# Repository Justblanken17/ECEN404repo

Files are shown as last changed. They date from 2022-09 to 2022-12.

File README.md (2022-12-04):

# ECEN404repo
reposit

Below Will detail what the Growable Space Habitat is, where to find files in this repo, as well as the deliverables at the end of 404 as well as hw to setup the project to run:

What is the Growable Space Habitat and our part in it? 

The Growable Space Habitat is a self-sustaining enclosure that is capable of keeping track of its health as well as make adjustments when needed. The Power Management
System is capable of supplying power to the MCU and AI/Data Processing systems while charging the battery and protecting it at the same time. The MCU system houses all of
the peripherals in the system such as sensors, fans, solenoids that monitor the habitat. The AI/Data Processing system is capable of classifying if plants within the 
system are healthy through 2 machine learning (ML) models. All of the data that s collected from the MCU, is then sent to the pi to be processed, which can send commands
to the MCU to adapt the habitat, ie, turn on the fan or solenoid etc. Everything that is sent to the pi and stored is then pushed to our User Interface System. 
The User Interface system takes the data that was pushed into the database and displays it on an app for the user to view. Data that can be viewed in the app include 
the different MCU boards, and for each of the boards, sensor data can be seen on graphs as well as historical data. The user can also see the images that the camera has
taken as well as if the plant is in a healthy state or not. 

## Our Deliverables for 404: ## 
1. User Interface:
    a. Be able to update real time photos and any of the sensor data on to graphs and display images through the app on the phone from 2 MCU boards
    b. firebase database communication with pi to receive data then send to the app for viewing.

2. AI/Data Processing:
     a. Working tomato leaf data set to be able to classify healthy or not
     b. working bell pepper leaf data set to be able to classify healthy or not (was not required but was completed for supplemental material)
     c. communicates with MCU as well as database

3. MCU:
     a. Control of O2, Temp/Humidity, CO2, Liquid Level, Water Flow, solenoid, fan. (for analog, the joystick is good enough for validation, since we do not have controlled substances of any of the analog sensor gases, as well as the voltage output that we get on the ethylene being good enough validation for the Analog type)
     b. Communicate all of the collected data from the mcu to the Pi
     c. Control other peripherals (solenoid and fan).(solenoid "clicking" is sufficient since there are not valves to "open/close" and fan being controlled on/off)

4. Power Management System  
     a. Provide power to the Pi and MCU systems
     b. Charge battery at same time that it is discharging (sun will not be out so power supply will mimic the solar panel) through the board and the controller.
     c. Protect the battery
     d. Monitoring was not able to work, talked it over with our sponsor Dr. Rising and she is aware and okay with it being passed down to the next ECEN team working on the project. The cell monitor is now an optional piece to this subsystem. 

5. Github Repository:
    a. Everything related to the project including schematics, designs, datasheets etc
    b. detailed write ups containing the purpose of each of the subsystems
    c. detailed description of the progress that was made and what needs to be done for the next team, also possible steps that they should take (advice).
   d. Shared with Rohith, Dr. Lusher and Dr. Rising

## How to navigate through our repo: ## 

In our Repo, the 4 of us have our own folders that have specific titles to make it easy to navigate. 
All datasheets, test scripts, altium designs and everything else related to the project is in this repo.

How to setup the project: 
1. The battery needs to first be connected to the terminal block on the BMS (positive on top most, negative on bottom most). The output of the BMS is to be connected to the MPPT controller. Any buck converters that are used need to be plugged into the mppt controller on the load termnals. These buck converters are sending power through wires to the MCU boards and the pi through a USB-A to USB-C cable. A solar panel, or or power supply can be plugged into the PV portion of the MPPT. The MCUs have already had the memory flashed, so the only setup there is connecting the sensors to it which will already be connected. Powering the MCUs come from the output of the buck converters to the terminal block on the MCU board. There is no setup for the User Interface side since it updates the data automatically as it is received. For the AI/Data Processing system the setup consists of running the scripts and then letting the programs do what they are told to do. Our projectwas meant to be autonomous, so that very little, to no human interference is necessary. 

Thanks!

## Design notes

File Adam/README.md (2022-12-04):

The idrectories stord here is the abstracted code for the MCU Firmware, Rsapberry Pi, Jupyter Notebook for training the binarry classifiers, and testing scripts for individual and system functionality.

## FIRMWARE ##

Each of the folders in the Firmware directory corresponds to the source and header file for each sensor.

## MACHINE_LEARNING ##

The folders store the jupyter nnotebooks that creates the data augmentation, train dataset, train csv, test dataset, model training.

## Test_Scripts ##

The python scripts here test the individual functionlity for of the system process to request i2c data, send data to database, classify, control cameras. etc.

## Running the system ##

Assuming that the system being used is the current image of the pi used, the following steps must be followed. In order to run main.py, the pi needs to have in its own sandbox i.e. virtual environment since Tensorflow has dependancies that affect the pi from running.

To activate the virtual environment:

cd Desktop/Project

source env/bin/activate

Adter it is activated mode back to the home directory and head to the test directory which is currently named Project_1:

cd ~
cd Desktop/Project_1

Run the serial_test script ot make sure that the serial data and serial clock line is intact and can receive data from the MCU:
python serial_test.py

Once it is verified and the corect values are being received, then head back to the home directory and proceed to the Demo directory:
cd ~
cd Demo

Run the main.py script so that it will constantly classify, retrieve data, and send data:
python main.py

## NOTE: ##
If a different database is used, you must change the db.ini file so that it can push data to the correct database. This was abstracted for ease of use in future changes of the database.

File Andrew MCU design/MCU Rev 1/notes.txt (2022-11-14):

1.8V regulator keeps breaking. MCU chip likely is drawing more than the rated 150mA.
LED power indicator circuit does not work.

Used 12MHz crystal oscillator, this means the clock configuration is max 198MHz, unlike the max 200MHz the curiosity 2.0 dev board is capable of.
Dev board link: https://www.microchip.com/en-us/development-tool/DM320209

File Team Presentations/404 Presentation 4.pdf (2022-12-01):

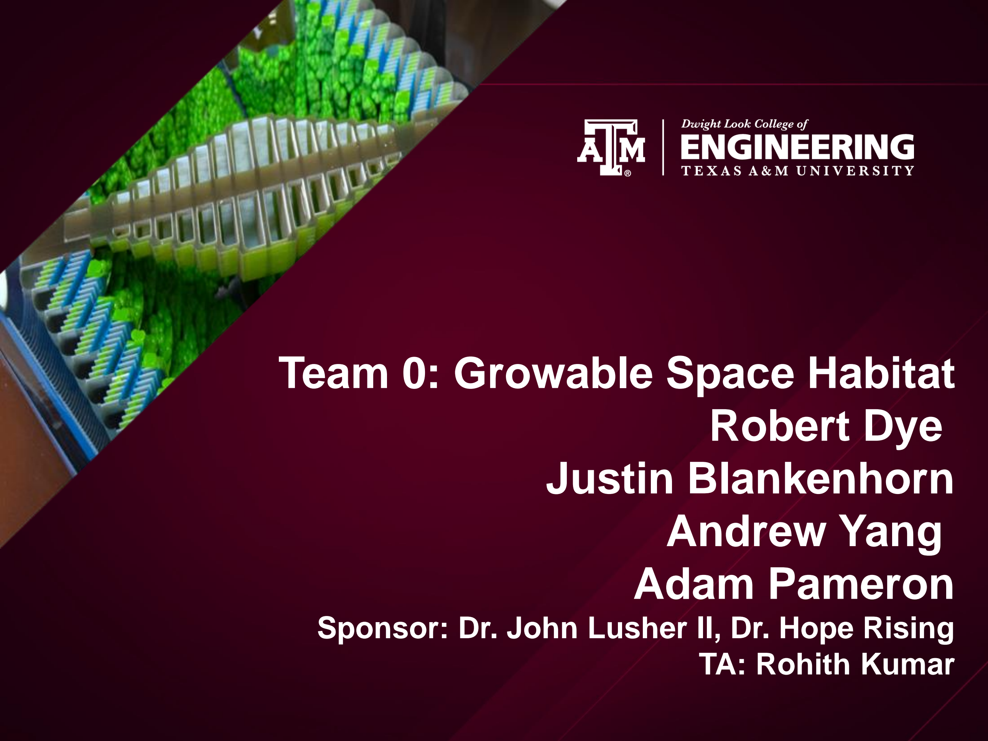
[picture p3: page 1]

# Team 0: Growable Space Habitat Robert Dye Justin Blankenhorn Andrew Yang Adam Pameron

### Sponsor: Dr. John Lusher II, Dr. Hope Rising TA: Rohith Kumar

# Project Summary

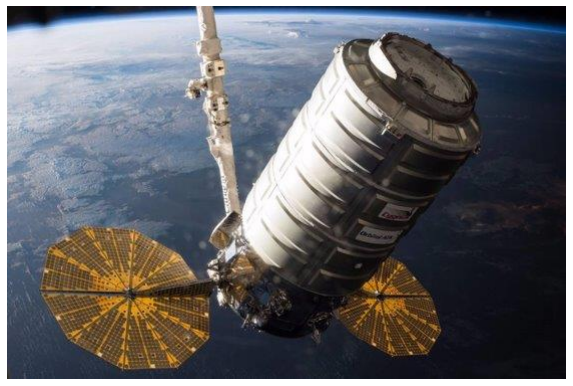
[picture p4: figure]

## - Current space operations require constant resupply

### – Costly ($20,000 per kg) – Inefficient and wasteful

## - Long term space missions need a sustainable food source

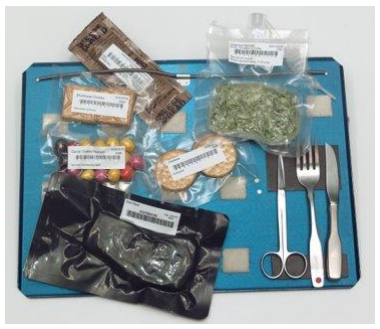
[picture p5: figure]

## - Project provides electrical infrastructure for a self-sustaining system capable of recycling agricultural products

# Project/Subsystem Overview

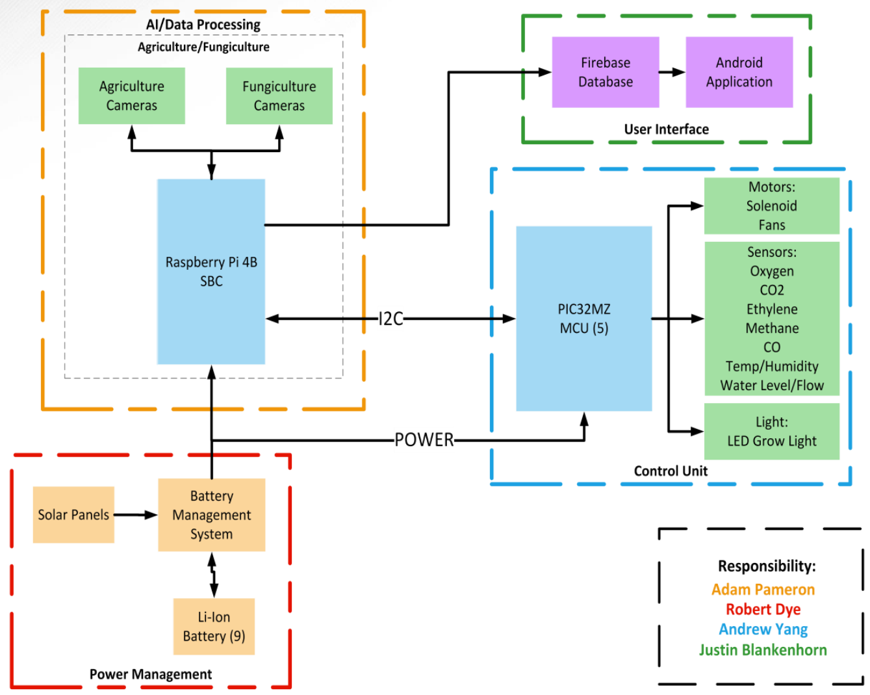
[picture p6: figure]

# Major Project Changes Since Last Time

Power Management:
- None
User Interface:
- None
AI/Data Processing:
- None
Microcontroller:
- None

## AI/Data Processing Subsystem

Adam Pameron

# - Create binary classifier using Convolutional Neural Network (CNN) Model

## – Baby Spinach

# - Collect sensor data from 5 microcontrollers - Send sensor data to database

# AI/Data Processing Subsystem

Adam Pameron
Accomplishments since last presentation

Ongoing progress/problems and plans until the next presentation

- Perform Stratified Cross Validation with augmented RGB Dataset
- Vertical Flip
- Gaussian Noise
- Blur
- Shearing
- Isolated each cameras to take photos at an interval period
- Built application code to repeat routines (classify, send image and state)
- Interfacing with microcontrollers using serial communication to request data, and validate all sensors data is collected and accurate

## AI/Data Processing Subsystem – Camera 1 and Camera 2 Photos

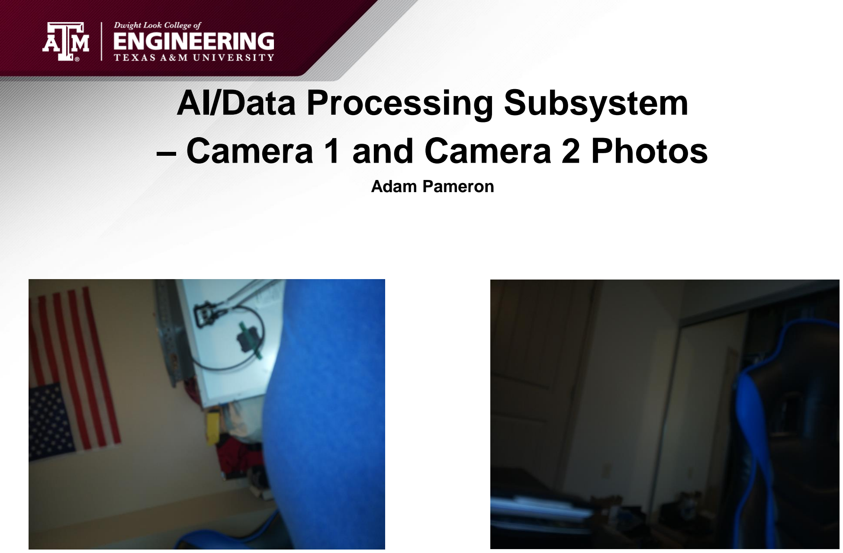
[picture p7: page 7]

Adam Pameron

## AI/Data Processing Subsystem – Camera 3 and Camera 4 Photos

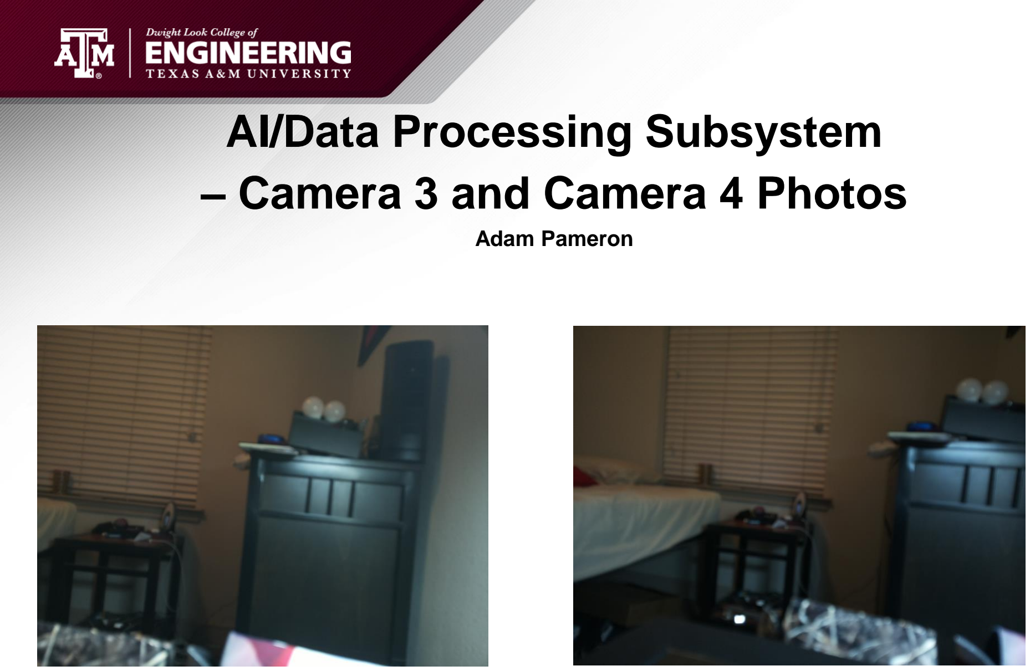
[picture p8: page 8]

Adam Pameron

## AI/Data Processing Subsystem

## - Total Size of Dataset

Adam Pameron

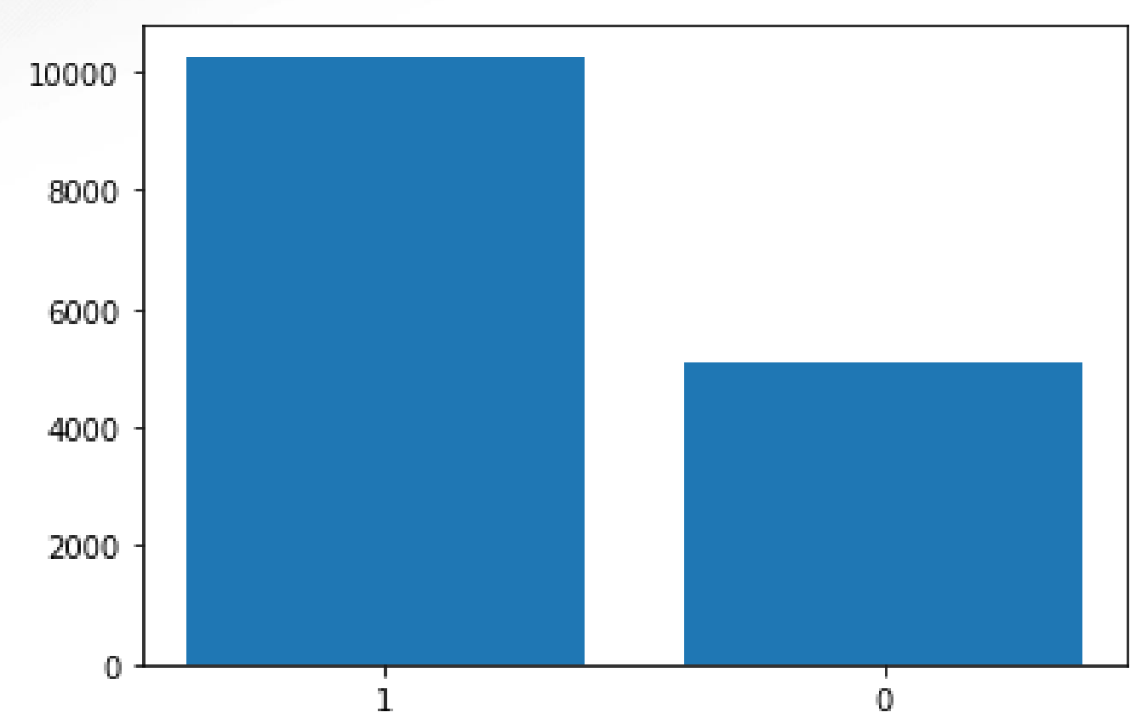
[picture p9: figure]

Healthy Set [0]: 5,084
Yellow Leaf Curl Set [1]: 10,264 Total Number of Images: 15,348

## AI/Data Processing Subsystem

## – with Gaussian Noise

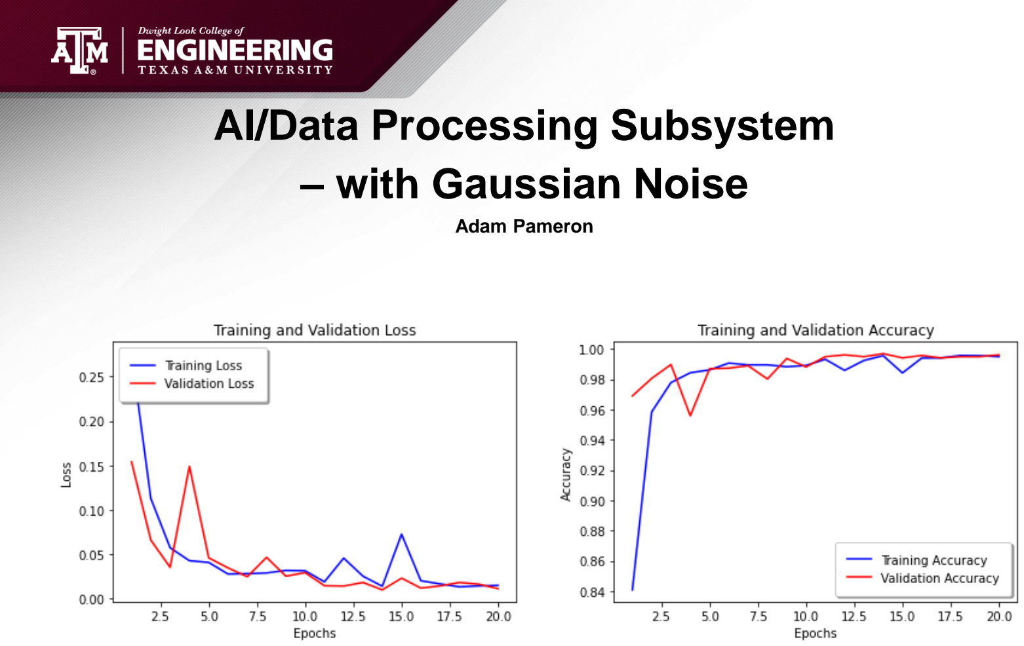
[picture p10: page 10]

Adam Pameron

## AI/Data Processing Subsystem

## – with Gaussian Noise

Adam Pameron

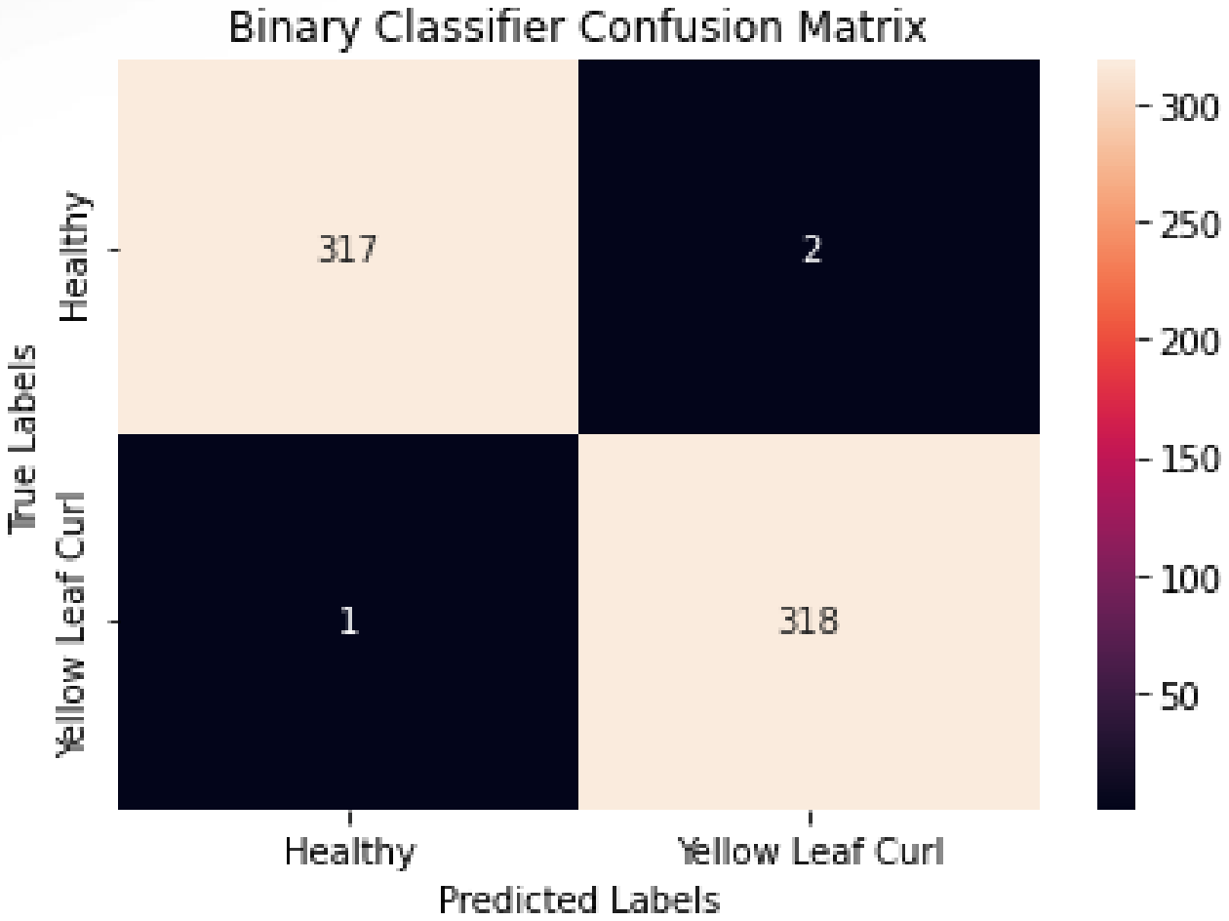
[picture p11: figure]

# - Provide power to PCBs that house the microcontrollers as well as the pi that will be used to control AI subsystem - BMS monitoring - Charging

# Power Management

Robert Dye

# Power Management

Robert Dye
Accomplishments since last presentation

Ongoing progress/problems and plans until the next presentation
- Soldered all components
- Powered MCU Subsystem
- Powered AI/Data Processing Subsystem
- Designed, Routed all 4 analog sensor circuits
- Keep performing testing on the BMS
- Code monitoring chips with BQ Studio

# Power Management

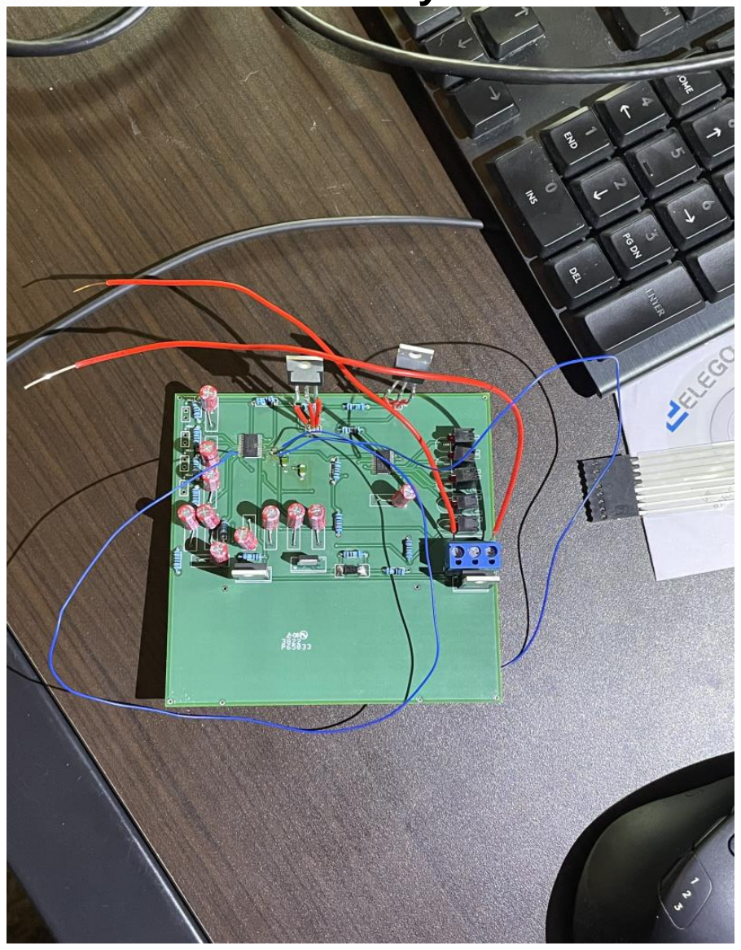
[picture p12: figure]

Robert Dye

# Power Management

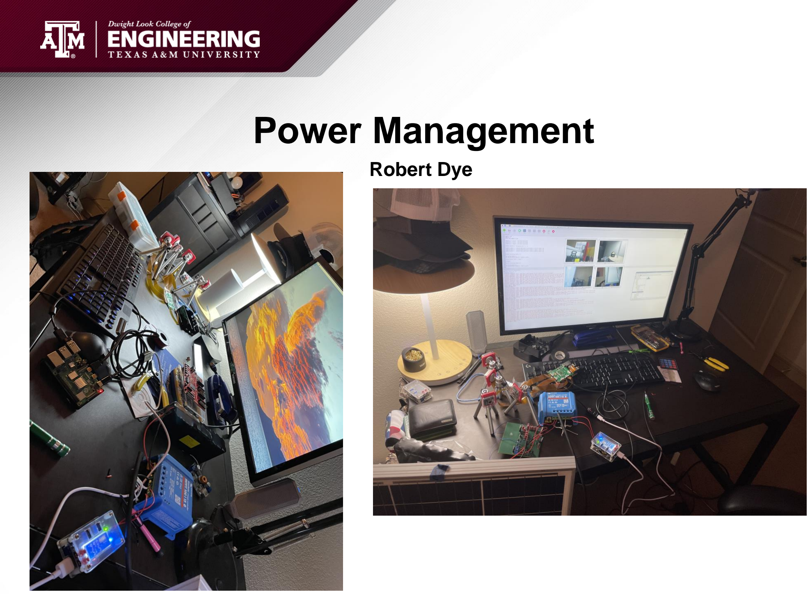
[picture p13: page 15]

Robert Dye

# Power Management

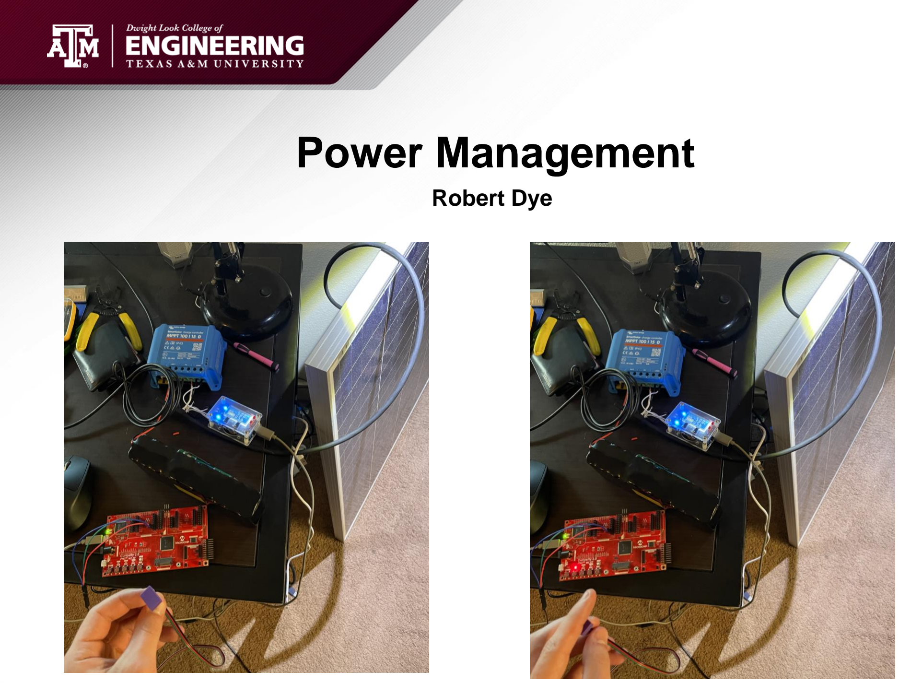
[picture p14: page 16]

Robert Dye

## Microcontroller

Andrew Yang

## - 200 Peripherals modularized between 5 microcontrollers

- 20 Oxygen, 20 CO2, 20 NO2, 20 Methane,

## 20 Ethylene, 20 Carbon monoxide, 12 Temp/Humidity, 4 water level, 4 water flow sensors

- 9 types of sensors using I2C, UART, Analog,

## or digital communication - 38 solenoids and 26 fans controlled using GPIO + switching circuit

# Microcontroller

Andrew Yang

Accomplishments
since last presentation

Ongoing progress/problems and plans until the next presentation
- Verified Water Level Sensor operation
- Designed Analog Sensor circuits
- Soldered over half of all components for the MCU
- Verify Temperature/Humidity I2C sensor operation
- Verify UART sensor operation
- Implement PWM logic for water flow sensor
- Design I2C multiplexer circuit for fan and solenoid switching

# Microcontroller

Andrew Yang

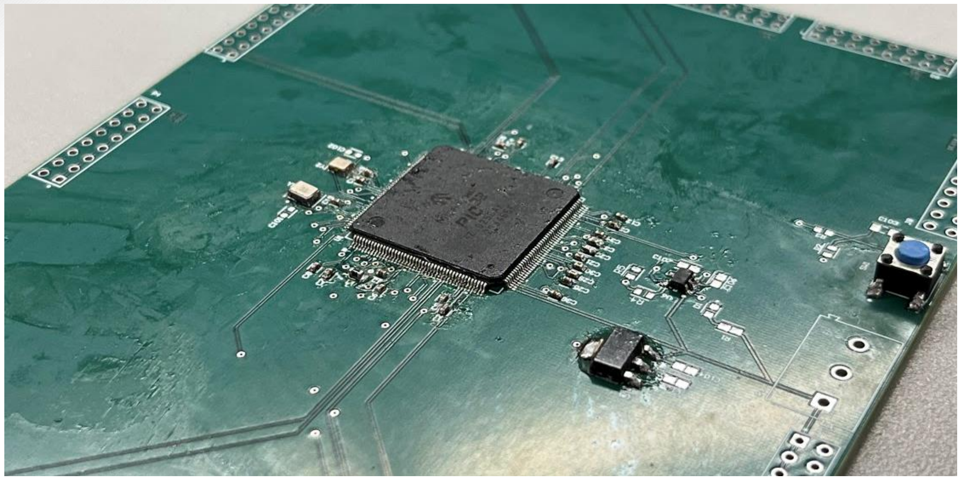
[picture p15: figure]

# Microcontroller

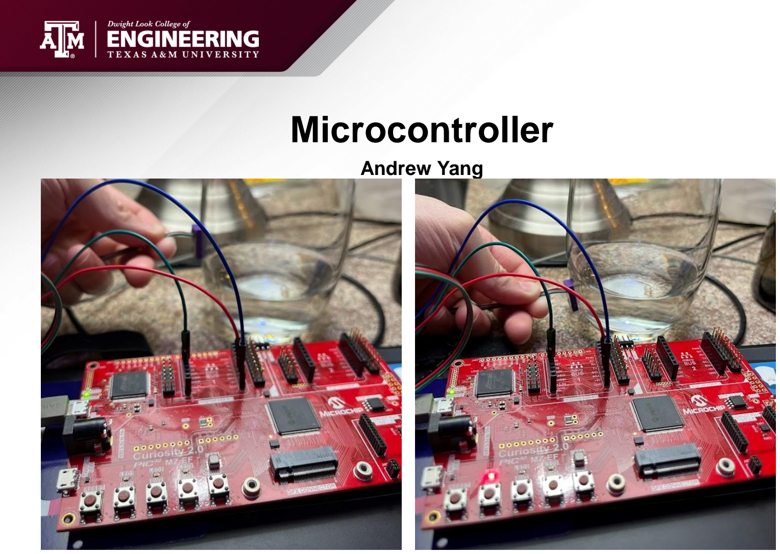
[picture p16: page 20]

Andrew Yang

# Microcontroller

Andrew Yang

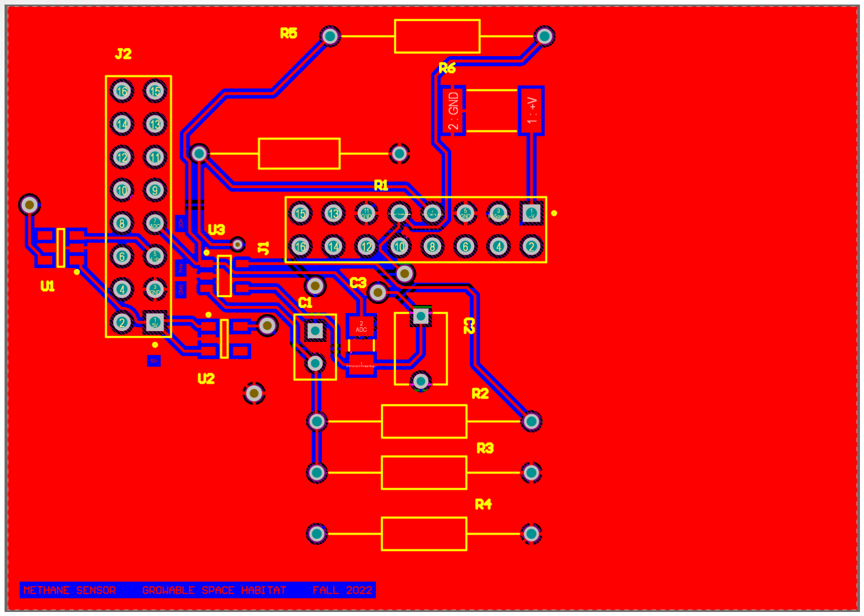
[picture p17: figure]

# Microcontroller

Andrew Yang

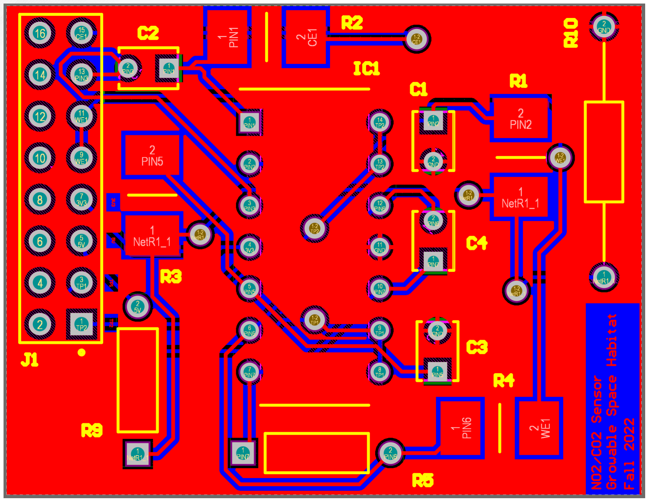
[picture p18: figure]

# Microcontroller

Andrew Yang

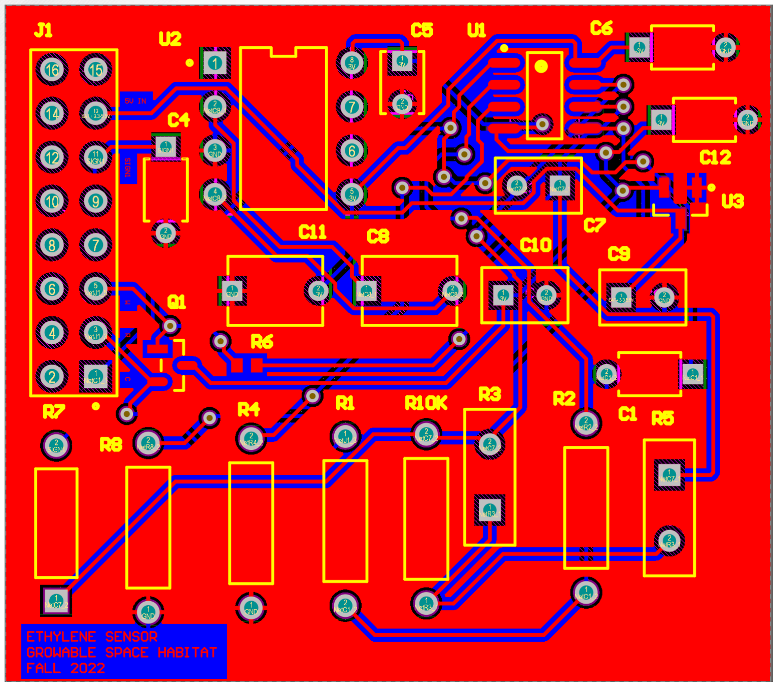
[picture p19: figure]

# User Interface

## - Display Data from MCU sensors on app - Visualize sensor values over time - Display camera pictures on app

# User Interface

Justin Blankenhorn

Accomplishments since last presentation

Ongoing progress/problems and plans until the next presentation
- Created Graphs for all sensors
- Differentiated graphs between Second + Minutes
- Included Axis's and scroll view for graph
- Improve formatting on graphs,
- Help on other subsystems

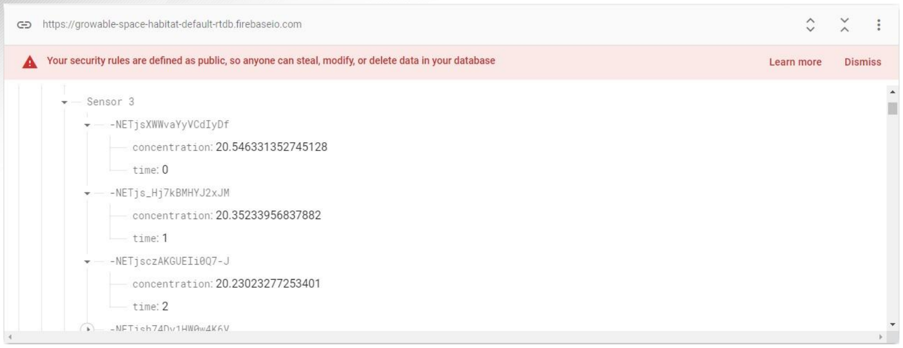
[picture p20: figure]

# User Interface

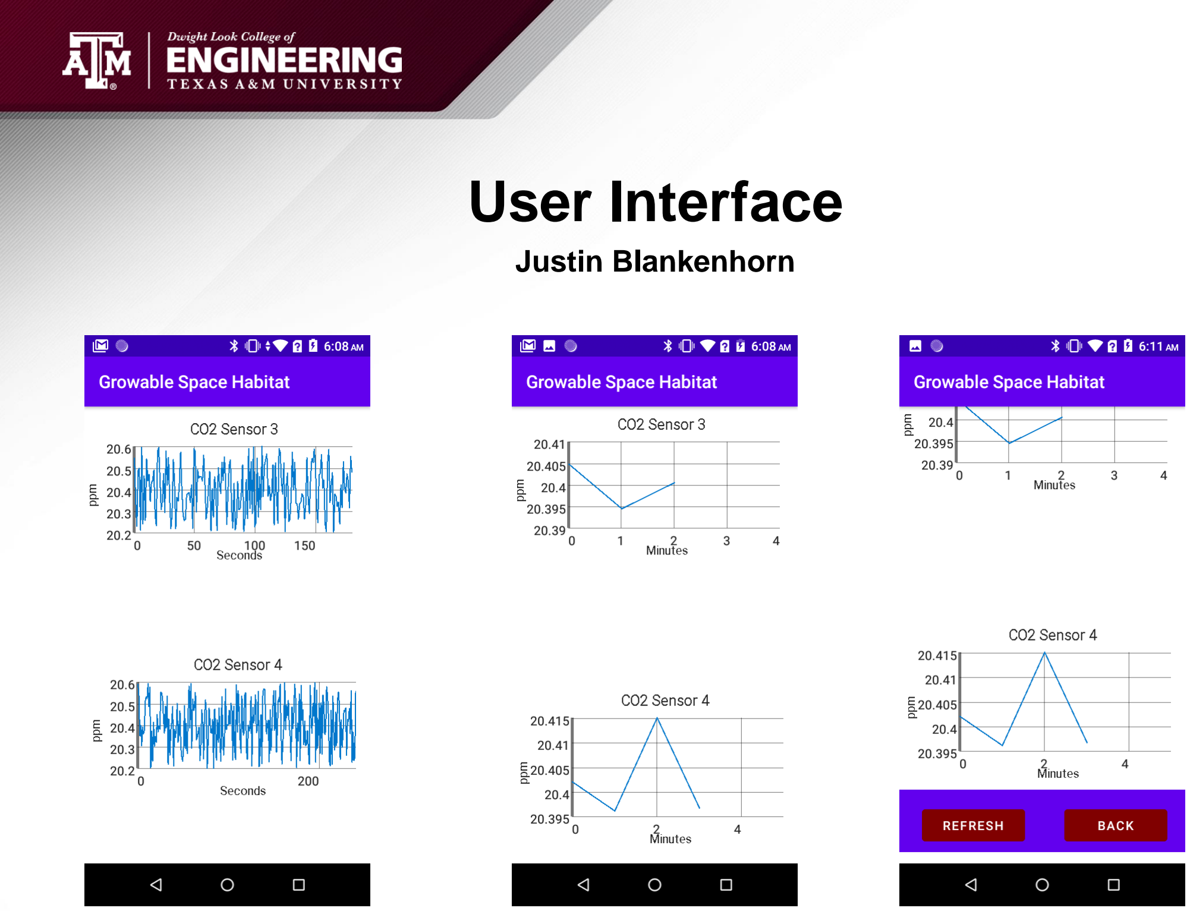
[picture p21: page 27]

Justin Blankenhorn

# Execution & Plan

# THANK YOU!

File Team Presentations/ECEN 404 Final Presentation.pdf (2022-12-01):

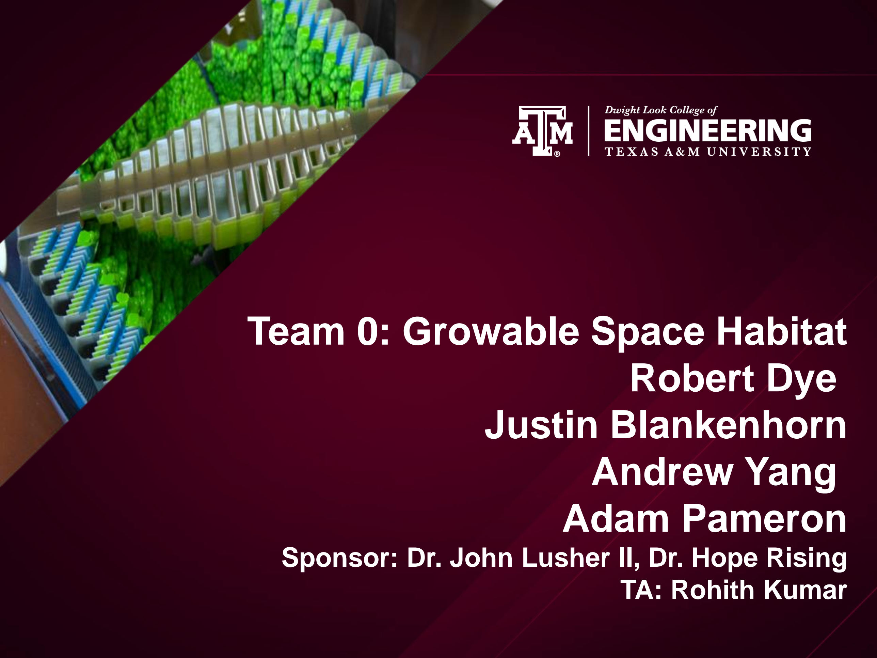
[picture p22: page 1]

# Team 0: Growable Space Habitat Robert Dye Justin Blankenhorn Andrew Yang Adam Pameron

### Sponsor: Dr. John Lusher II, Dr. Hope Rising TA: Rohith Kumar

# Project Overview

## - Current space operations require constant resupply

### – Costly ($20,000 per kg) – Inefficient and wasteful

## - Long term space missions need a sustainable food source


## - Project provides electrical infrastructure for a self-sustaining system capable of recycling agricultural products

# System-Level Requirements

- Power Management-
– Power MCU, AI/Data Processing – Charge battery through solar panel – Monitor battery pack
- MCU-
– Control Peripherals
– 1 of each type of sensor (I2C, Analog, UART, Digital (External clock)
– Replacing 1 analog with 2 extra others (Temp/Humidity, solenoid)
- AI/Data Processing-
– Binary Classifying model for tomato leaf as well as oyster mushroom (proxy data) – Reliably request data from MCU and send the data to the database
- User Interface-
– Display data from MCU sensors on an app
– Graph sensor values over time, Graph health of plant (1-healthy, 0-not) – Display camera pictures

# Project/Subsystem Block Diagram

## AI/Data Processing Accomplishments

Adam Pameron

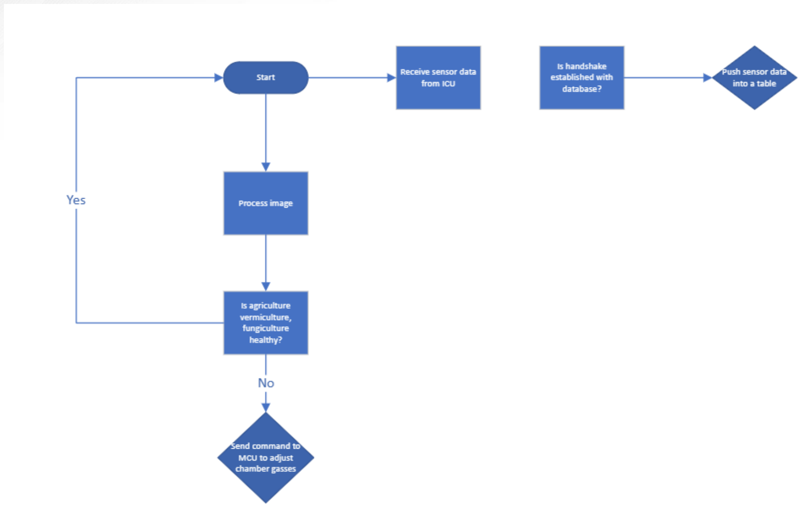
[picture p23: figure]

## AI/Data Processing Subsystem

## – Train Accuracy 4 Folds

Adam Pameron

## AI/Data Processing Subsystem

## – Validation Accuracy 4 Folds

Adam Pameron

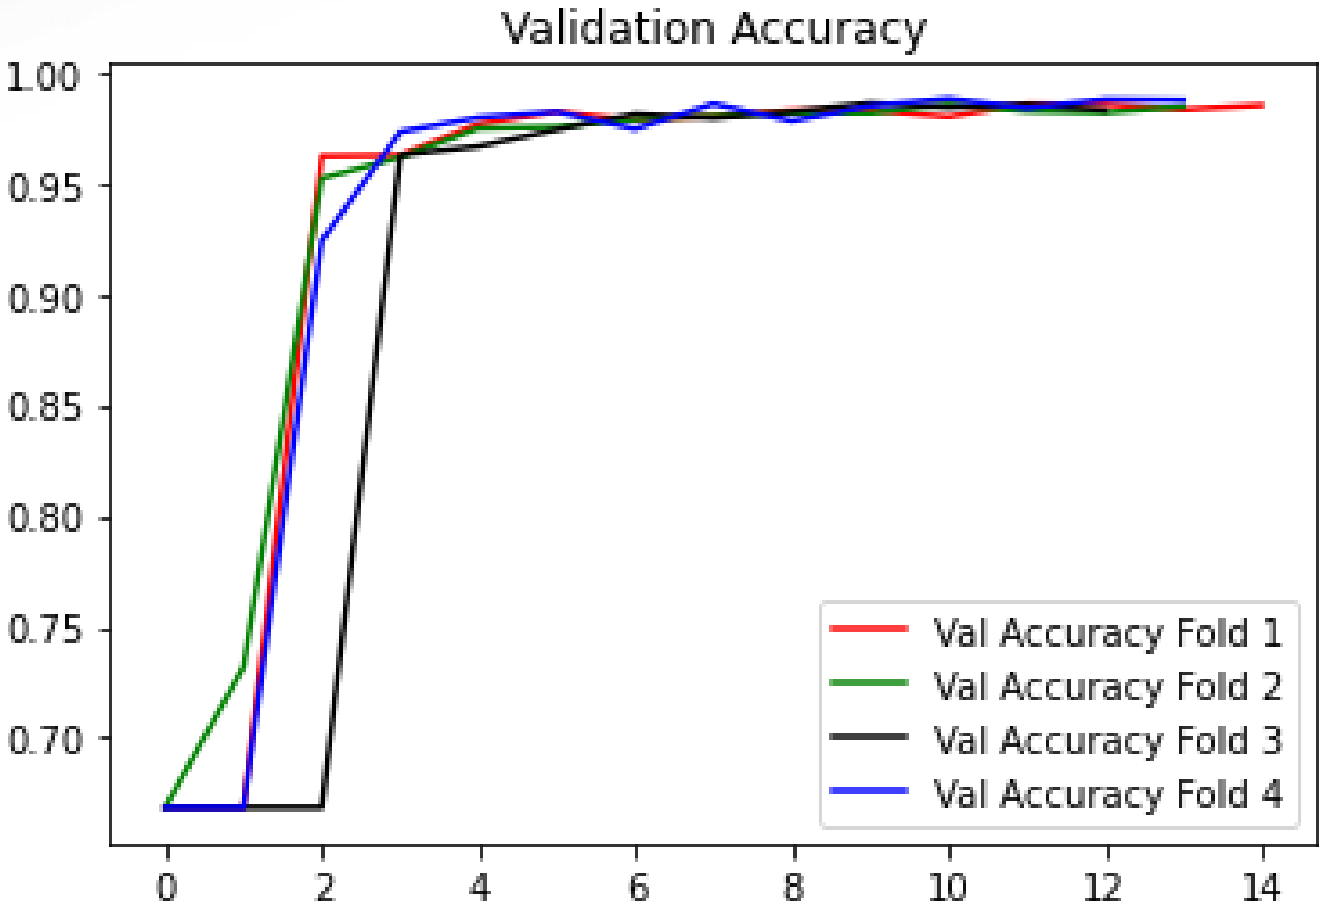
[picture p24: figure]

## AI/Data Processing Subsystem

## – Validation Accuracy 4 Folds

Adam Pameron

## AI/Data Processing Subsystem

## – Training and Validation Accuracy Fold 4

Adam Pameron

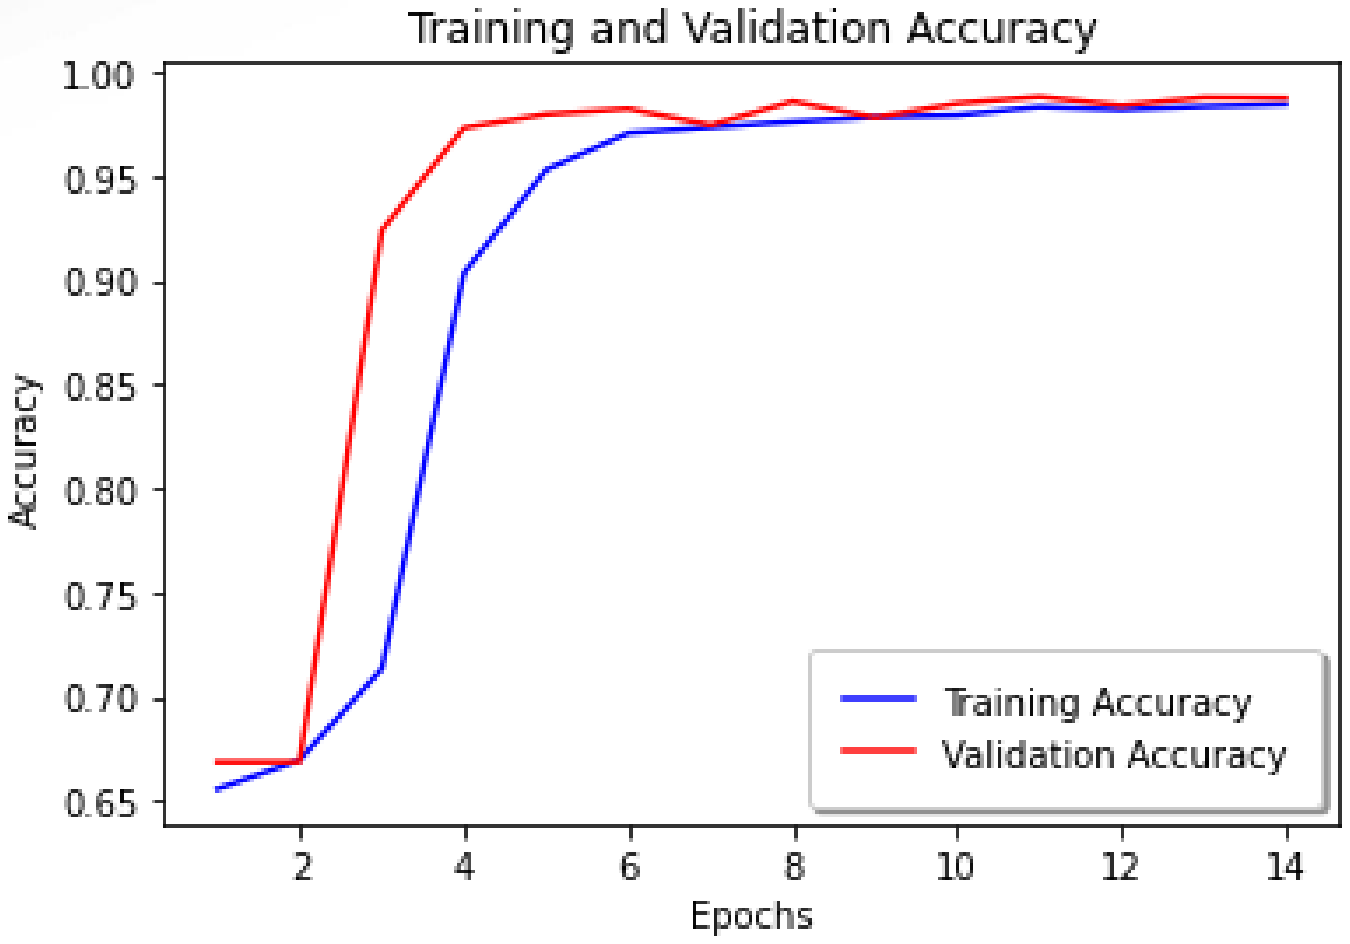
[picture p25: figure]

## AI/Data Processing Subsystem

## – Confusion Matrix Fold 4

Adam Pameron

## AI/Data Processing Subsystem

## – Pi and PIC32 CO2 Values

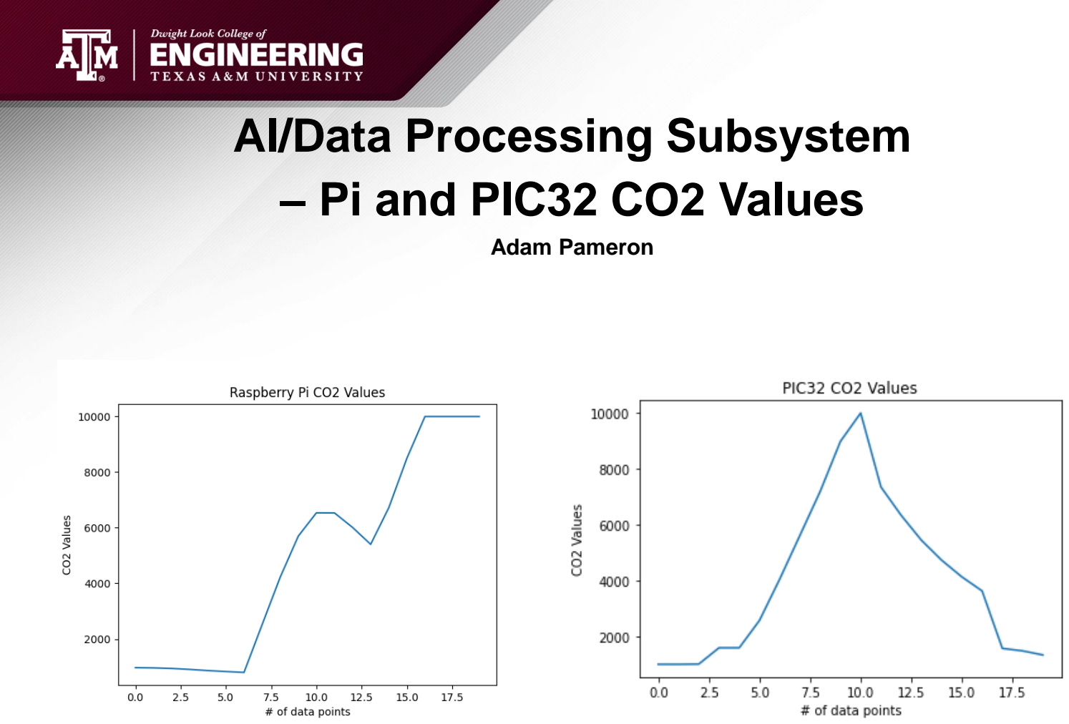
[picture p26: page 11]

Adam Pameron

## AI/Data Processing Subsystem

## – Arduino and PIC32 O2 Values

Adam Pameron

## AI/Data Processing Subsystem


Adam Pameron

# Power Management Accomplishments

Robert Dye

- BMS PCB
- Charging/discharging/power delivery
- Overcurrent Protection
- Design and solder 4 analog sensor circuits and PCBs with Andew


## Power Management Accomplishments Robert Dye

## Power Management Accomplishments Robert Dye


## Power Management Accomplishments Robert Dye

## Power Management Accomplishments Robert Dye


## Power Management Accomplishments Robert Dye

## Power Management Accomplishments Robert Dye


# Power Management

Robert Dye

# Power Management Previous Graphs

Robert Dye

# Power Management - Graphs from video

Robert Dye; Bat Voltage (V); Current (A)

Battery Voltage vs. Time

Current vs. Time

Time (hr:min:sec)

# Microcontroller Accomplishments

Andrew Yang

- Designed and soldered PIC32MZ microcontroller
- Designed and soldered 3 analog sensor circuits and PCBs with Robert
- Wrote firmware to operate water flow, temp/humidity, CO2, O2, water level, water flow sensor, solenoid, and fan with Adam


## Microcontroller Accomplishments Andrew Yang


## Microcontroller Accomplishments Andrew Yang

## Microcontroller Accomplishments Andrew Yang


## Microcontroller Accomplishments Andrew Yang

## Microcontroller Accomplishments Andrew Yang


## Microcontroller Accomplishments Andrew Yang

# User Interface Accomplishments

- Display real time sensor data
- Displaying graph's of sensor data of time, with different windows of duration
- Display camera pictures


# User Interface – General Format

Justin Blankenhorn

# User Interface – Validating edge cases 1


# User Interface – Validating edge cases 2

# Data Integration


# Data Integration


# System and Validation Results Videos


# System and Validation Results Videos


# System and Validation Results Videos


# System and Validation Results Full Video


# Conclusion Requirements

•Power Management-
•Built a BMS PCB that can power 2 other systems and charge battery via solar through BMS
•Built separate sensor circuits required to run the sensors
•MCU-
•Built PCB that can control various peripherals
- Built separate sensor circuits required to run the sensors
•AI/Data Processing-
•User Interface-
•Created and app and database where data can be displayed, analyzed, and pushed through

# Conclusions Learned

- Designing of PCB schematics and boards
- Microchip programming
- Concise reading of datasheets
- Reading convolution and neural networks
- Database/app creation and integration
- Sensor configurations, sensor amplifying techniques
- Microcontroller coding
- Cross team communication
- Project and time management skills
- If it can go wrong, it will go wrong

# Conclusion What Went Right and Wrong

- Rights-
- AI/Data Processing machine learning model classification
- App/Database Creation
- Integration of all 4 subsystems went smoothly
- Powering/Charging
- Control of different peripherals through both dev board and MCU
- Wrongs:
- Multiple design errors and other issues caught after PCBs soldered, had to re do designs
- Monitoring of pack and cell issues (contact with Dr. Lusher and TI) no resolutions
- Initial approach with mySQL database, changed to firebase for easier integration

# Project Mitigation

- Tasks to try to get done by demo
- Potentially 1 of the Analog sensors to work (replace with 2 others)
- Potential battery pack monitoring

# THANK YOU!

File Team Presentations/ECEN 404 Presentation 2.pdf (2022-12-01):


# Team 0: Growable Space Habitat Robert Dye Justin Blankenhorn Andrew Yang Adam Pameron

### Sponsor: Dr. John Lusher II, Dr. Hope Rising TA: Rohith Kumar

# Project Summary


## - Current space operations require constant resupply

### – Costly ($20,000 per kg) – Inefficient and wasteful

## - Long term space missions need a sustainable food source


## - Project provides electrical infrastructure for a self-sustaining system capable of recycling agricultural products

# Project/Subsystem Overview


# Major Project Changes Since Last Time

Power Management:
- Finalize 1 complete system by end of semester
User Interface:
- Converted to firebase
AI/Data Processing:
- Only working on baby spinach, no oyster mushroom
Microcontroller:
- Finalize 1 complete system by end of semester

# Project Timeline

Milestone | Expected Time
Obtain significant data for charging of battery pack | September 9
Order BMS PCB | September 9
Order MCU PCB | September 9
Integrate Raspberry Pi and 5 MCUs | September 17
Integrate all sensors | September 23
Solder all BMS PCB components | October 12
Solder all MCU PCB components | October 14
Finalize and debug all BMS connections | October 23
Integrate Raspberry Pi and Database | October 30
Retrieve Baby Spinach Data from Horticulture Team and create CNN Model | October 30
Finalize and debug all sensors | October 30

## AI/Data Processing Subsystem

Adam Pameron

# - Create binary classifier using Convolutional Neural Network (CNN) Model

## – Baby Spinach – Oyster Mushroom

# - Collect sensor data from 5 microcontrollers - Send sensor data to database

# AI/Data Processing Subsystem

Adam Pameron
Accomplishments since last presentation

Ongoing progress/problems and plans until the next presentation

- Perform data augmentation with data set
- Grayscale
- Vertical Flip
- Gaussian Blur
- Shearing
- Even number of data
- Request data from I2C with oxygen sensor
- Send trend data to Firebase Database
- Waiting for Horticulture Team to fully grow Healthy and Nitrogen Deficient Baby Spinach to collect images [est. October]
- Send images to Firebase database
- Interfacing with microcontrollers using serial communication to request data, and validate all sensors data is collected and accurate
- Build application code to repeat all routines (classify, request data, send data) at a set time

## AI/Data Processing Subsystem - Parameters

Adam Pameron


Modified LeNet Architecture

## AI/Data Processing Subsystem


Adam Pameron

## AI/Data Processing Subsystem

Adam Pameron


## AI/Data Processing Subsystem

Adam Pameron


## - Send oxygen data to Firebase – Time – Concentration

# - Provide power to PCBs that house the microcontrollers as well as the pi that will be used to control AI subsystem - BMS monitoring - Charging

# Power Management

Robert Dye

# Power Management

Robert Dye
Accomplishments since last presentation | Ongoing progress/problems and plans until the next presentation
- Performed extensive testing on battery and solar panel with smaller loads • Ordered PCB | • Perform same tests with a heavier load • Solder Components on PCB once it arrives • Help MCU subsystem

# Power Management


Robert Dye

## Microcontroller

Andrew Yang

## - 200 Peripherals modularized between 5 microcontrollers

- 20 Oxygen, 20 CO2, 20 NO2, 20 Methane,

## 20 Ethylene, 20 Carbon monoxide, 12 Temp/Humidity, 4 water level, 4 water flow sensors

- 9 types of sensors using I2C, UART, Analog,

## or digital communication - 38 solenoids and 26 fans controlled using GPIO + switching circuit

# Microcontroller

Andrew Yang

Accomplishments
since last presentation

Ongoing progress/problems and plans until the next presentation
- Redesigned MCU PCB
- Verified Oxygen I2C sensor operation
- Ordered new MOSFET for
solenoid switching
- Verify Temperature/Humidity I2C sensor operation
- Verify UART sensor operation
- Implement PWM logic for water flow sensor
- Design op-amp circuit and verify analog sensor operation
- Design I2C multiplexer circuit for fan and solenoid switching

# Microcontroller


Andrew Yang

# Microcontroller

Andrew Yang


# Microcontroller

Andrew Yang


# Microcontroller


Andrew Yang

Expected Result from Arduino

Result from Microchip Dev Board

# User Interface

## - Display Data from MCU sensors on app - Visualize sensor values over time - Display camera pictures on app

# User Interface

Justin Blankenhorn

Accomplishments since last presen tation | Ongoing progress/problems and plans until the next presentation
- Established connection between Android Studio and Firebase App • Set up Firebase database sensor data display on app for 3 MCU units | • Add display from other MCU units • Display images to app using firebase • Develop graphs for sensor data over time

# User Interface


Justin Blankenhorn

# Parts Ordering Status

Susbsytem | Item | Quantity | Price
AI/ Data Processing Subsystem | Raspberry Pi 4 8GB Kit | 1 | $169.95
| Arducam IMX519 Quad-Camera Kit | 1 | $169.99
| Arducam Camera Case and Mini Tripod | 4 | $11.99
Power Management Subsystem | 100 watt solar panel | 2 | $100
| BQ78350DBTR-R1A Fuel Guage | 10 | $4.00
| BQ7693000DBT Battery Monitor | 10 | $4.00
| 14.8V 13Ah Battery Pack | 6 | $194.00
| DC Power Supply | 1 | N/A
| Victron MPPT Controller | 1 | $137
| DROK Buck Converter | 10 | $14.00
| PCB | 5 | $63.64
Control Unit Subsystem | PIC32MZ2025DAK176-V/2J | 10 | $19.58
| Gravity: Electrochemical Oxygen Sensor | 10 | $43.12
| 004-0-0053 CO2 Sensor | 8 | $53.36
| 110-507 NO2 Sensor | 4 | $20.00
| IR33BC Methane Sensor | 4 | $262.63
| ME3-C2H4 Ethylene Sensor | 8 | $91.95
| SEN0485 Liquid Level Sensor | 8 | $9.90
| SEN0227 Temperature/Humidity Sensor | 8 | $22.50
| 110-102 CO Sensor | 8 | $20.00
| PCB | 5 | $126.37
| PG164140 Pickit4 Programmer | 2 | $65.32
| Mini solenoid | 4 | $12.49
| NF-A4x10 5V Fan | 8 | $13.95
| Water Flow Sensor | 4 | $10.99
| 2N7000 N-MOS | 2 | $5.50
| BS170 N-MOS | 2 | $7.25
User Interface | Android EL 6C Cell Phone | 1 | $73.00
Total | | | $6,832.78

# Execution & Plan


# THANK YOU!

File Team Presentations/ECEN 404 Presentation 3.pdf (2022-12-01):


# Team 0: Growable Space Habitat Robert Dye Justin Blankenhorn Andrew Yang Adam Pameron

### Sponsor: Dr. John Lusher II, Dr. Hope Rising TA: Rohith Kumar

# Project Summary


## - Current space operations require constant resupply

### – Costly ($20,000 per kg) – Inefficient and wasteful

## - Long term space missions need a sustainable food source


## - Project provides electrical infrastructure for a self-sustaining system capable of recycling agricultural products

# Project/Subsystem Overview


# Major Project Changes Since Last Time

Power Management:
- None
User Interface:
- None
AI/Data Processing:
- Possibility of no spinach data sets Microcontroller:
- Ordered MCU PCB

# Project Timeline

Milestone | Expected Time
Obtain significant data for charging of battery pack | September 9
Order BMS PCB | September 9
Order MCU PCB | September 9
Integrate Raspberry Pi and 5 MCUs | September 17
Integrate all sensors | September 23
Solder all BMS PCB components | October 12
Solder all MCU PCB components | October 14
Finalize and debug all BMS connections | October 23
Integrate Raspberry Pi and Database | October 30
Retrieve Baby Spinach Data from Horticulture Team and create CNN Model | October 30
Finalize and debug all sensors | October 30

## AI/Data Processing Subsystem

Adam Pameron

# - Create binary classifier using Convolutional Neural Network (CNN) Model

## – Baby Spinach – Oyster Mushroom

# - Collect sensor data from 5 microcontrollers - Send sensor data to database

# AI/Data Processing Subsystem

Adam Pameron
Accomplishments since last presentation

Ongoing progress/problems and plans until the next presentation

- Perform data augmentation with RGB data set
- Vertical Flip
- Gaussian Noise
- Blur
- Shearing
- Send trend data to all sensors in database
- Send image to database
- Waiting for Horticulture Team to fully grow Healthy and Nitrogen Deficient Baby Spinach to collect images [est. October]
- Interfacing with microcontrollers using serial communication to request data, and validate all sensors data is collected and accurate
- Build application code to repeat all routines (classify, request data, send data) at a set time

## AI/Data Processing Subsystem - Parameters

Adam Pameron


## AI/Data Processing Subsystem - Augmentation with Roboflow


Adam Pameron

## AI/Data Processing Subsystem – without Gausian Noise


Adam Pameron

## AI/Data Processing Subsystem – without Gaussian Noise


Adam Pameron

## AI/Data Processing Subsystem – with Gaussian Noise


Adam Pameron

## AI/Data Processing Subsystem – with Gaussian Noise

Adam Pameron


# - Provide power to PCBs that house the microcontrollers as well as the pi that will be used to control AI subsystem - BMS monitoring - Charging

# Power Management

Robert Dye

# Power Management

Robert Dye
Accomplishments since last presentation | Ongoing progress/problems and plans until the next presentation
- Received PCB • Ordered BOM for PCB • Designed couple of sensor circuits for MCU PCB • Ran more tests with larger load | • Solder Components on PCB once they arrives • Help MCU subsystem

# Power Management


Previous | Robert Dye | New

## Microcontroller

Andrew Yang

## - 200 Peripherals modularized between 5 microcontrollers

- 20 Oxygen, 20 CO2, 20 NO2, 20 Methane,

## 20 Ethylene, 20 Carbon monoxide, 12 Temp/Humidity, 4 water level, 4 water flow sensors

- 9 types of sensors using I2C, UART, Analog,

## or digital communication - 38 solenoids and 26 fans controlled using GPIO + switching circuit

# Microcontroller

Andrew Yang

Accomplishments
since last presentation

Ongoing progress/problems and plans until the next presentation
- Ordered MCU PCB, comes in this week
- Designed 2/3 Analog Sensor amplifier circuits schematics
- Verify Temperature/Humidity I2C sensor operation
- Verify UART sensor operation
- Implement PWM logic for water flow sensor
- Design I2C multiplexer circuit for fan and solenoid switching
- Solder MCU board

# Microcontroller

Andrew Yang


# Microcontroller

Andrew Yang


# Microcontroller

Andrew Yang


# Microcontroller

Andrew Yang


# User Interface

## - Display Data from MCU sensors on app - Visualize sensor values over time - Display camera pictures on app

# User Interface

Justin Blankenhorn

Accomplishments since last presentation

Ongoing progress/problems and plans until the next presentation
- Finished restructuring database to use firebase
- Was able to get pictures from firebase to update
- Was able to display sensor data graphs for oxygen sensors
- Improve formatting on graphs, add to other sensors
- Work on getting graph to display over time

# User Interface


Justin Blankenhorn

# Parts Ordering Status

Susbsytem | Item | Quantity | Price
AI/ Data Processing Subsystem | Raspberry Pi 4 8GB Kit | 1 | $169.95
| Arducam IMX519 Quad-Camera Kit | 1 | $169.99
| Arducam Camera Case and Mini Tripod | 4 | $11.99
Power Management Subsystem | 100 watt solar panel | 2 | $100
| BQ78350DBTR-R1A Fuel Guage | 10 | $4.00
| BQ7693000DBT Battery Monitor | 10 | $4.00
| 14.8V 13Ah Battery Pack | 6 | $194.00
| DC Power Supply | 1 | N/A
| Victron MPPT Controller | 1 | $137
| DROK Buck Converter | 10 | $14.00
| PCB | 5 | $63.64
Control Unit Subsystem | PIC32MZ2025DAK176-V/2J | 10 | $19.58
| Gravity: Electrochemical Oxygen Sensor | 10 | $43.12
| 004-0-0053 CO2 Sensor | 8 | $53.36
| 110-507 NO2 Sensor | 4 | $20.00
| IR33BC Methane Sensor | 4 | $262.63
| ME3-C2H4 Ethylene Sensor | 8 | $91.95
| SEN0485 Liquid Level Sensor | 8 | $9.90
| SEN0227 Temperature/Humidity Sensor | 8 | $22.50
| 110-102 CO Sensor | 8 | $20.00
| PCB | 5 | $126.37
| PG164140 Pickit4 Programmer | 2 | $65.32
| Mini solenoid | 4 | $12.49
| NF-A4x10 5V Fan | 8 | $13.95
| Water Flow Sensor | 4 | $10.99
| 2N7000 N-MOS | 2 | $5.50
| BS170 N-MOS | 2 | $7.25
User Interface | Android EL 6C Cell Phone | 1 | $73.00
Total | | | $6,832.78

# Execution & Plan


# THANK YOU!

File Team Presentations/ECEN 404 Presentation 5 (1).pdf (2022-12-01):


# Team 0: Growable Space Habitat Robert Dye Justin Blankenhorn Andrew Yang Adam Pameron

### Sponsor: Dr. John Lusher II, Dr. Hope Rising TA: Rohith Kumar

# Project Summary


## - Current space operations require constant resupply

### – Costly ($20,000 per kg) – Inefficient and wasteful

## - Long term space missions need a sustainable food source


## - Project provides electrical infrastructure for a self-sustaining system capable of recycling agricultural products

# Project/Subsystem Overview


# Major Project Changes Since Last Time

Power Management:
- None
User Interface:
- Will display data on health of system AI/Data Processing:
- None
Microcontroller:
- None

## AI/Data Processing Subsystem

Adam Pameron

# - Create binary classifier using Convolutional Neural Network (CNN) Model

## – Baby Spinach [Proxy: Tomato Leaves]

# - Collect sensor data from microcontrollers - Send sensor data to database

# AI/Data Processing Subsystem

Adam Pameron
Accomplishments since last presentation

Ongoing progress/problems and plans until the next presentation

- Perform Stratified Cross Validation with augmented RGB Dataset
- Used SGD Optimizer
- Configured UART serial communication
- Validated sensor data with trusted Pi data
- Configured I2C serial communication
- Controller and Peripheral Mode
- Validated Sensor Data with trusted Arduino data
- Deployed model to Pi to validate classification
- Built application code to repeat routines (classify, send image and state)
- Created specialized functions to abstract routine
- Further validation of sensor data
- Build application code for PIC32
- Create specialized functions to abstract routine

## AI/Data Processing Subsystem – Train Accuracy 4 Folds

Adam Pameron


## AI/Data Processing Subsystem – Validation Accuracy 4 Folds

Adam Pameron


## AI/Data Processing Subsystem – Validation Accuracy 4 Folds

Adam Pameron

## AI/Data Processing Subsystem – Training and Validation Accuracy Fold 4

Adam Pameron


## AI/Data Processing Subsystem – Confusion Matrix Fold 4

Adam Pameron


## AI/Data Processing Subsystem – Pi and PIC32 CO2 Values


Adam Pameron

## AI/Data Processing Subsystem – Arduino and PIC32 O2 Values


Adam Pameron

## AI/Data Processing Subsystem


Adam Pameron

# - Provide power to PCBs that house the microcontrollers as well as the pi that will be used to control AI subsystem - BMS monitoring - Charging

# Power Management

Robert Dye

# Power Management

Robert Dye
Accomplishments since last presentation | Ongoing progress/problems and plans until the next presentation
- Powered all subsystems at the same time • Soldered analog Sensor PCBs | • Keep performing testing on the BMS • Code monitoring chips with BQ Studio

# Power Management

Robert Dye


# Power Management - Voltage/Time graph current 1.06/1.25

Robert Dye


# Power Management - % Health/Time graph current 1.06/1.25


Robert Dye

## Microcontroller

Andrew Yang

# - 200 Peripherals modularized between 5 microcontrollers - UART, I2C, Analog, Digital, Digital Counter, GPIO switch

# Microcontroller

Andrew Yang

Accomplishments
since last presentation

Ongoing progress/problems and plans until the next presentation
- Validated MCU operation
- Ordered Analog Sensor PCBs Rev. 2
- Implement counter logic for water flow sensor
- Solder and validate analog sensor boards
- Flash MCU with dev board code

## Microcontroller

## Andrew Yang


# Microcontroller

Andrew Yang


# User Interface

## - Display Data from MCU sensors on app - Visualize sensor values over time - Display camera pictures on app

# User Interface

Justin Blankenhorn

Accomplishments since last presentation

Ongoing progress/problems and plans until the next presentation
- Configured Graphs in terms of hours, days, weeks, years
- Use dropdown button instead of buttons
- Included data + graphs on plant health with pictures
- Reconfigured graphs to lower noise
- Put Camera pictures on separate pages
- Reformat graphs to align with Pi internal clock
- Work on formatting

# User Interface - Graphs


Justin Blankenhorn

# User Interface – System Health


# Data Integration


# Data Integration


# Execution & Plan


# THANK YOU!

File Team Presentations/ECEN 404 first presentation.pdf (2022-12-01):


# Team 0: Growable Space Habitat Bi-Weekly Update 1

### Andrew Yang Adam Pameron Rob Dye Justin Blankenhorn Sponsor: Lusher

TA: TA Name Intro should take 30 seconds

# Project Summary (30 seconds)

## - What is the problem that we are solving

## - High-level summary of what system does to solve the problem

Picture / Diagram
here

## Project/Subsystem Overview (45 seconds)

Diagram showing subsystems – with labels showing subsystem owners

Bullets giving essential
system/subsystem
characteristics

If major changes in
subsystems, show before and after … see next slide

## Major Project Changes for 404 (45 seconds)

Bullets on changes due to team membership changes -- describe how subsystem assignments, roles, project will change to accommodate team changes

Bullets on MAJOR changes in project direction due to learning from 403. If stuff didn’t work out now is the time to redirect
-- eg custom to COTS, MCU
changes, application change, major change in communication technology, …

# Project Timeline (30 seconds)

High level figure showing where you
are at in the project, what’s completed, what’s underway – it should take about 30 seconds to summarize where you are in the timeline

-- Save discussion for subsystem update
-- Save detail for execution plan & validation plan status

# Subsystem 1 (45 seconds)

Owner

Accomplishments since 403 XX hrs of effort | Ongoing progress/problems and plans until the next presentation
What has been accomplished (not just started) – is it back up and running from 403? | What are you going to accomplish in the next 2 weeks

-- “Started, began, initiated…” are not accomplishments --You do not need to have any accomplishment on some updates if you describe in “Ongoing” what work you have been doing
-- Make things here specific and measurable/verifiable

# Subsytem 1 (45 seconds)

Owner of Subsystem 1

Interesting figure related to your subsystem
progress

Detail on what works,
what doesn’t, what is
changing

# Parts Ordering Status (30 seconds)

- Most parts orders for 404 should be placed very soon.
- Provide summary of what is ordered but not received and what remains to be ordered.
- When do you expect to have all parts?

# Execution & Plan (Show for 45 seconds)

- Execution plan
- Your team planned milestones for completion of any remaining subsystem functionality, integration of specific subsystems, test, and validation plans should be presented.
- Milestones should have owners … things like final integration can be group owned
- Gantt chart – should indicate some 404 progress.
- Try to complete all subsystem function in next 3 weeks.
- Try to complete all integration 2 weeks before demo to allow for system validation and documentation

# Final slide – thank your audience

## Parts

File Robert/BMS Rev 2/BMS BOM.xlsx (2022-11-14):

Comment | Description | Designator | Footprint | LibRef | Quantity | Supplier | Link | Unit Price
 | Capacitor | C0, C1, C2, C3, C4, C5, C6, C13, C14, C15, C16 | RAD-0.3 | Cap | 55 | Mouser | 860020772005 Wurth Elektronik | Mouser (https://www.mouser.com/ProductDetail/Wurth-Elektronik/860020772005) | 0.12 | 6.6
 | Multicell Battery | CELL1, CELL2, CELL3, CELL4 | BAT-2 | Battery | 20 | Already Have
 | Default Diode | D1 | SMC | Diode | 5 | Mouser | https://www.mouser.com/ProductDetail/Vishay-General-Semiconductor/SMAJ16A-E3-61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 | 0.46 | 2.3
691101710003 | Series 101 - 5.00 mm Horizontal Entry Modular with Pressure Clamp WR-TBL, 3 pin | J3 | 691101710003 | CMP-1502-03257-1 | 5 | Already Have
 | Typical INFRARED GaAs LED | LED1, LED2, LED3, LED4, LED5 | LED-0 | LED0 | 8 | Mouser | HLMP-1700-B00A1 Broadcom / Avago | Mouser (https://www.mouser.com/ProductDetail/Broadcom-Avago/HLMP-1700-B00A1?qs=jT9z6tsiFNl96EfZdviG8A%3D%3D) | 1.98 | 15.84
 | N-Channel Power MOSFET, | Q1, Q3 | TO-220AB | NMOS-2, | 10 | Digikey | https://www.digikey.com/en/products/detail/nexperia-usa-inc/PSMN2R7-30PL-127/2530351 | 2.17 | 21.7
 | P-Channel Power Mosfet | Q2 |  |  | 5 | Digikey | AOI21357 Alpha & Omega Semiconductor Inc. | Discrete Semiconductor Products | DigiKey (https://www.digikey.com/en/products/detail/alpha-omega-semiconductor-inc/AOI21357/9951422) | 0.78 | 3.9
 | N-Channel MOSFET, P-Channel MOSFET | Q5 | E3 | MOSFET-N, MOSFET-P | 5 | Texas Instruments | CSD17381F4 | Buy TI Parts | TI.com (https://www.ti.com/product/CSD17381F4/part-details/CSD17381F4) | 0.146 | 0.73
 | P-channel Mosfet | Q6 |  |  | 5 | Digikey | IRF9Z30PBF-BE3 Vishay Siliconix | Discrete Semiconductor Products | DigiKey (https://www.digikey.com/en/products/detail/vishay-siliconix/IRF9Z30PBF-BE3/12396431) | 2.74 | 13.7
 | Resistor Kit | 'R0, R1, R2, R3, R4, R5, R8, R9, R10, R11, R12, R13, R14, R15, R16, R19 | n/a | n/a | 1 | Amazon | Amazon.com: 1280 Pieces 64 Values Resistor Kit, 1% Assorted Resistors 1 Ohm-10M Ohm 1/4W Metal Film Resistors Assortment for DIY Projects and Experiments : Industrial & Scientific (https://www.amazon.com/Resistor-Assorted-Resistors-Assortment-Experiments/dp/B07L851T3V) | 10.99 | 10.99
 | Thermistor | R6, R7 | 6-0805_N | Res Thermal | 10 | Mouser | NHQ103B375T10 Amphenol Advanced Sensors | Mouser (https://www.mouser.com/ProductDetail/Amphenol-Advanced-Sensors/NHQ103B375T10?qs=tktsEd1V4BmbPnjuxVqGuA%3D%3D) | 2.72 | 27.2
BQ7693000DBT | No Description Available | U1 | DBT0030A_N | BQ7693000DBT | 5 | Already Have
BQ78350DBT-R1 | IC BATTERY MGMT CTRLR 30TSSOP | U2 | FP-DBT0030A-IPC_C | CMP-04911-000039-1 | 5 | Already Have
 |  |  |  |  |  |  |  | Total Price | 102.96 | Note: total of all is actually less for bulk discounts
 |  |  |  |  |  | Texas Instruments Cart | Your Shopping Cart | TI store (https://www.ti.com/store/ti/en/cart)
 |  |  |  |  |  | Mouser Cart | My Shopping Cart - Mouser (https://www.mouser.com/Cart/)
 |  |  |  |  |  | Digikey Cart | Digi-Key: Shopping Cart (digikey.com) (https://www.digikey.com/ordering/shoppingcart?lang=en)

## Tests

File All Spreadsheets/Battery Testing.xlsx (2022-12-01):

Battery Testing w Solar Panel 20mA load |  |  |  | Battery Discharge .4A load
 |  |  |  |  |  |  |  | Battery Voltage | Time | Charge Percentage | Amps MCU | Amps pi | tot Amps
Bat voltage | Time | Charge Current | charge level % | Bat Voltage | Time |  |  | 14.49 | 0:05:00 | 88.92857143 | 0.32 | 0.74 | 1.06
12.06 | 0:00:02 | 5.04 | 2.142857143 | 13.77 | 0:00:00 | 4.98 |  | 14.48 | 0:10:00 | 88.57142857 | 0.32 | 0.74 | 1.06
12.07 | 0:00:04 | 5.04 | 2.5 | 13.76 | 0:01:00 | 4.98 |  | 14.47 | 0:15:00 | 88.21428571 | 0.32 | 0.74 | 1.06
12.08 | 0:00:06 | 5.04 | 2.857142857 | 13.75 | 0:02:20 | 4.98 | snip | 14.47 | 0:20:00 | 88.21428571 | 0.32 | 0.74 | 1.06
12.09 | 0:00:08 | 5.04 | 3.214285714 | 13.74 | 0:03:50 | 4.98 |  | 14.46 | 0:25:00 | 87.85714286 | 0.32 | 0.93 | 1.25
12.1 | 0:00:10 | 5.04 | 3.571428571 | 13.74 | 0:04:10 | 4.98 |  | 14.44 | 0:30:00 | 87.14285714 | 0.32 | 0.93 | 1.25
12.11 | 0:00:12 | 5.04 | 3.928571429 | 13.73 | 0:05:20 | 4.98 |  | 14.43 | 0:35:00 | 86.78571429 | 0.32 | 0.93 | 1.25
12.12 | 0:00:14 | 5.04 | 4.285714286 | 13.73 | 0:06:47 | 4.98 |  | 14.43 | 0:40:00 | 86.78571429 | 0.32 | 0.74 | 1.06
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

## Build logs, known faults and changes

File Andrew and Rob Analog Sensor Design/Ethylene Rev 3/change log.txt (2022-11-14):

Fixed +3v and -3v polarity issue on op amp.

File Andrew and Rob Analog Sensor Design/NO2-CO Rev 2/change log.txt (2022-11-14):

Added 1V regulator
Added ground pin
Corrected Test point connections
Redid layout/Rerouted

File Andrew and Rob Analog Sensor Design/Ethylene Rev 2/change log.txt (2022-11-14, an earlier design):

Added ground pin connection
Reoriented parts/rerouted components

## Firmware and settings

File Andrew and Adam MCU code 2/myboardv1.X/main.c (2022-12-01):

/*******************************************************************************
  Main Source File

  Company:
    Microchip Technology Inc.

  File Name:
    main.c

  Summary:
    This file contains the "main" function for a project.

  Description:
    This file contains the "main" function for a project.  The
    "main" function calls the "SYS_Initialize" function to initialize the state
    machines of all modules in the system
 *******************************************************************************/

// *****************************************************************************
// *****************************************************************************
// Section: Included Files
// *****************************************************************************
// *****************************************************************************

#include <stddef.h>                     // Defines NULL
#include <stdbool.h>                    // Defines true
#include <stdlib.h>                     // Defines EXIT_FAILURE
#include "definitions.h"                // SYS function 
#include <stdio.h>
#include <string.h>

//Test message buffers
char helloBuffer[] = "Hello World\n\r";
char msgBuffer[200];


//I2C oxygen sensor
#define ADDRESS_0   0x70
#define ADDRESS_1   0x71
#define ADDRESS_2   0x72
#define ADDRESS_3   0x73  ///< iic slave Address select
#define OCOUNT      100   ///< oxygen Count Value
#define OXYGEN_DATA_REGISTER 0x03   ///< register for oxygen data
#define USER_SET_REGISTER    0x08   ///< register for users to configure key value manually
#define AUTUAL_SET_REGISTER  0x09   ///< register that automatically configure key value
#define GET_KEY_REGISTER     0x0A   ///< register for obtaining key value


//I2C temp/humidity sensor
#define ERROR_I2C_TIMEOUT                     998
#define ERROR_BAD_CRC                         999
#define SHT20_I2C_ADDR                        0x40

#define TRIGGER_TEMP_MEASURE_HOLD             0xE3
#define TRIGGER_HUMD_MEASURE_HOLD             0xE5
#define TRIGGER_TEMP_MEASURE_NOHOLD           0xF3
#define TRIGGER_HUMD_MEASURE_NOHOLD           0xF5
#define WRITE_USER_REG                        0xE6
#define READ_USER_REG                         0xE7
#define SOFT_RESET                            0xFE
#define USER_REGISTER_RESOLUTION_MASK         0x81
#define USER_REGISTER_RESOLUTION_RH12_TEMP14  0x00
#define USER_REGISTER_RESOLUTION_RH8_TEMP12   0x01
#define USER_REGISTER_RESOLUTION_RH10_TEMP13  0x80
#define USER_REGISTER_RESOLUTION_RH11_TEMP11  0x81
#define USER_REGISTER_END_OF_BATTERY          0x40
#define USER_REGISTER_HEATER_ENABLED          0x04
#define USER_REGISTER_DISABLE_OTP_RELOAD      0x02

#define MAX_WAIT                              100
#define DELAY_INTERVAL                        10
#define SHIFTED_DIVISOR                       0x988000
#define MAX_COUNTER                           (MAX_WAIT/DELAY_INTERVAL)




//water flow sensor global variables
uint16_t water_rate = 0.0;
float water_flow = 0;
float water_convert = 31.0;


//Oxygen sensor global variables
float o2val = 0;

/* Function:
    void fan_switch()

  Summary:
    Toggles GPIO pin RPE9 on and off for 1 second. Returns the state of the fan.

  Remarks:
    The GPIO pin needs to be assigned in Harmony 3.
 *Tools -> Harmony 3 configurator
 *In Harmony 3 configurator, Tools -> Pin Configuration -> Pin Table -> Scroll down to GPIO
 *-> Find an available pin number from the altium schematic -> Scroll right and find the pin on the Pin Table
 *-> Pin Settings -> Find the pin and select Direction (TRIS) to Out
*/

int fan_switch(){
    GPIO_RE9_Toggle(); //toggles pin RPE9
    CORETIMER_DelayMs(1000);
    return GPIO_RE9_Get();
}

/* Function:
    void solenoid_switch()

  Summary:
    Toggles GPIO pin RPA9 on and off for 1 second. Returns the state of the solenoid.

  Remarks:
    The GPIO pin needs to be assigned in Harmony 3.
 *Tools -> Harmony 3 configurator
 *In Harmony 3 configurator, Tools -> Pin Configuration -> Pin Table -> Scroll down to GPIO
 *-> Find an available pin number from the altium schematic -> Scroll right and find the pin on the Pin Table
 *-> Pin Settings -> Find the pin and select Direction (TRIS) to Out
*/

int solenoid_switch(){
    GPIO_RA9_Toggle(); //toggles pin RPE9
    CORETIMER_DelayMs(1000);
    return GPIO_RA9_Get();
}



/* Function:
    void readFlash()

  Summary:
 * For Oxygen Sensor

  Remarks:
   
*/

float key = 0.0;
float oxygenData[OCOUNT] = {0.0};

void readFlash(uint16_t addr) {          // Updated
    static uint8_t value = 0;

    static uint8_t temp_key_register = GET_KEY_REGISTER;
    I2C1_WriteRead(addr, &temp_key_register, 1, &value, 1);
    CORETIMER_DelayMs(100);

    if (value == 0) {
        key = 20.9 / 120.0;
    }
    else {
        key = ((float) value) / 1000.0;
    }
}

/* Function:
    void calibrate()

  Summary:
 * For oxygen sensor
  Remarks:
   
*/
void calibrate(float vol, float mv, uint16_t addr) {       // FIX THIS TO WORK
    uint8_t keyValue = vol * 10;
    if(mv < 0.000001 && mv > (-0.000001) ) {

        static uint8_t temp_user_reg = USER_SET_REGISTER;
        I2C1_Write(ADDRESS_3, &temp_user_reg, sizeof(temp_user_reg));
        I2C1_Write(ADDRESS_3, &keyValue, sizeof(keyValue));     // Verify if this is right

    }
    else {
        keyValue = (vol / mv) * 1000;

        static uint8_t temp_actual_reg = AUTUAL_SET_REGISTER;
        I2C1_Write(ADDRESS_3, &temp_actual_reg, sizeof(temp_actual_reg));
        I2C1_Write(ADDRESS_3, &keyValue, sizeof(keyValue));

    }
}
/* Function:
    void getAverageNum()

  Summary:
 * Gets the average of the raw oxygen data to eliminate noise
  Remarks:
   
*/

float getAverageNum(float bArray[], uint8_t len) {
    uint8_t i = 0;
    double bTemp = 0;
    for (i = 0; i < len; i++) {
        bTemp += bArray[i];
    }
    return bTemp / ((float) len);
}

/* Function:
    void getOxygenData()

  Summary:
 * Returns oxygen data
  Remarks:
   
*/
float getOxygenData(uint8_t collectNum, uint16_t addr) {
    uint8_t rxbuf[10] = {0};
    static uint8_t i = 0, j = 0;
    readFlash(addr);
    CORETIMER_DelayMs(500);

    if (collectNum > 0) {
        for (j = collectNum - 1; j > 0; j--) {
            oxygenData[j] = oxygenData[j-1];
        }

        static uint8_t temp_oxygen_reg = OXYGEN_DATA_REGISTER;
        I2C1_WriteRead(addr, &temp_oxygen_reg, 1, &rxbuf[0], 3);
        while (I2C1_IsBusy())
        {
            // DO NOTHING...
        }
        oxygenData[0] = ((key) * (((float) rxbuf[0]) + ((float) rxbuf[1] / 10) + ((float) rxbuf[2] / 100)));
        char testBuf[100];
        sprintf(testBuf, "%x, %x, %x", rxbuf[0], rxbuf[1], rxbuf[2]);
        UART3_Write(&testBuf, strlen(testBuf));
        if (i < collectNum) {
            i++;
        }
        
        return getAverageNum(oxygenData, i);
    }
    else {
        return -1.0;
    }

}


/* Function:
    void Timer2_Handler()

  Summary:
 * Counts to 1000 milliseconds and counts pulses from the water flow sensor.
  Remarks:
   
*/
void Timer2_Handler(uint32_t status, uintptr_t context)
{
    static uint16_t counter = 0;
    counter++;

    if (counter > 999)
    {
        water_rate = TMR3;
        TMR3 = 0x0000;
        counter = 0;
        water_flow = water_rate/water_convert;
    }

}


int co2_val = 0;
/* Function:
    void getCarbonDioxideData()

  Summary:
 * Reads Carbon Dioxide data from sensor.
  Remarks:
   
*/
float getCarbonDioxideData(void) {

    uint8_t address1 = 0xFE;
    UART2_WriteByte(address1);
    uint8_t address2 = 0x44;

    UART2_WriteByte(address2);
    uint8_t address3 = 0x00;

    UART2_WriteByte(address3);
    uint8_t address4 = 0x08;

    UART2_WriteByte(address4);
    uint8_t address5 = 0x02;

    UART2_WriteByte(address5);
    uint8_t address6 = 0x9F;

    UART2_WriteByte(address6);
    uint8_t address7 = 0x25;

    UART2_WriteByte(address7);

    uint8_t rxdata[10] = {0};
    rxdata[0] = UART2_ReadByte();
    CORETIMER_DelayMs(100);
    rxdata[1] = UART2_ReadByte();
    CORETIMER_DelayMs(100);
    rxdata[2] = UART2_ReadByte();
    CORETIMER_DelayMs(100);
    rxdata[3] = UART2_ReadByte();
    CORETIMER_DelayMs(100);
    rxdata[4] = UART2_ReadByte();
    CORETIMER_DelayMs(100);
    rxdata[5] = UART2_ReadByte();
    CORETIMER_DelayMs(100);
    rxdata[6] = UART2_ReadByte();
    CORETIMER_DelayMs(100);
//    char buffer[200];

    float return_val = ((int) rxdata[3]*256 + (int) rxdata[4]);
    return_val = return_val * (100.0/2000.0);
//    sprintf(buffer, "CO2 Value: %f percent\n\r", return_val);
//    UART3_Write(&buffer, strlen(buffer));
    return return_val;
        
}



//temp humidity sensor
/* Function:
    uint8_t checkCRC()

  Summary:
 * Error checking function for temp/humidity sensor
  Remarks:
   
*/

uint8_t checkCRC(uint16_t message_from_sensor, uint8_t check_value_from_sensor) {
    uint32_t remainder = (uint32_t)message_from_sensor << 8;
    remainder |= check_value_from_sensor;
    uint32_t divisor = (uint32_t) SHIFTED_DIVISOR;
    int i = 0;
    for(i = 0; i < 16; i++) {
        if(remainder & (uint32_t)1 << (23 - i)) {
            remainder ^= divisor;
        }
        divisor >>= 1;
    }
    
    return (uint8_t) remainder;
}

/* Function:
    void readFlash()

  Summary:

  Remarks:
   
*/
uint16_t readValue(uint8_t cmd) {
    uint8_t tempRead[3] = {0};
    I2C1_Write(SHT20_I2C_ADDR, &cmd, 1);
//    CORETIMER_DelayMs(100);
    CORETIMER_DelayMs(200);
    I2C1_Read(SHT20_I2C_ADDR, &tempRead[0], 3);

    while (I2C1_IsBusy())
    {
        // DO NOTHING...
    }
    uint8_t msb = tempRead[0];
    uint8_t lsb = tempRead[1];
    uint8_t checksum = tempRead[2];

    uint16_t rawValue = ((uint16_t) msb << 8) | (uint16_t) lsb;
    if(checkCRC(rawValue, checksum) != 0) {
        return (ERROR_BAD_CRC);
    }
    return rawValue & 0xFFFC;
}

float readTemperature(void) {
    uint16_t rawTemperature = readValue(TRIGGER_TEMP_MEASURE_NOHOLD);
    char readBuf[200];
    if (rawTemperature == ERROR_I2C_TIMEOUT || rawTemperature == ERROR_BAD_CRC) {
        UART3_Write(&helloBuffer, strlen(helloBuffer));
        return rawTemperature;
    }
    float tempTemperature = rawTemperature * (175.72 / 65536.0);
    float realTemperature =  tempTemperature - 46.85;
    sprintf(readBuf, "Real Temperature: %f C\n\r", realTemperature);
    UART3_Write(&readBuf, strlen(readBuf));
    return realTemperature;
}

float readHumidity(void) {
    uint16_t rawHumidity = readValue(TRIGGER_HUMD_MEASURE_NOHOLD);
    if (rawHumidity == ERROR_I2C_TIMEOUT || rawHumidity == ERROR_BAD_CRC) {
        return rawHumidity;
    }
    float tempRH = rawHumidity * (125.0 / 65536.0);
    float rh = tempRH - 6.0;
    char humidBuf[200];
    sprintf(humidBuf, "Relative Humidity: %f%c\n\r", rh, 37);
    UART3_Write(&humidBuf, strlen(humidBuf));
    return (rh);
}

float collectedData[20] = {0.0};
bool data_request1 = false;
uint8_t globalPtr = 0;
uint8_t pos = 0;
bool APP_I2C_CALLBACK(I2C_SLAVE_TRANSFER_EVENT event, uintptr_t contextHandle) {
    bool isSuccess = true;
    uint8_t read_val = 0;

    switch(event)
    {
        case I2C_SLAVE_TRANSFER_EVENT_ADDR_MATCH:
            globalPtr = 0;
            pos = 0;
            break;

        case I2C_SLAVE_TRANSFER_EVENT_RX_READY:
            read_val = I2C2_ReadByte();
            if (read_val == 0x10) { // Move solenoid
            }
            else if (read_val == 0x20) {
                data_request1 = true;
            }
            break;

        case I2C_SLAVE_TRANSFER_EVENT_TX_READY:
            if (data_request1 == true) {
                if (pos == 4) {
                    pos = 0;
                    globalPtr++;
                }
                I2C2_WriteByte(*((unsigned char*) &collectedData[globalPtr] + pos));
                pos++;
                UART6_Write(&helloBuffer, strlen(helloBuffer));

            }
            if (globalPtr == 6) {
                data_request1 = false;
            }
            break;

        default:
            break;
    }

    return isSuccess;

}

int main(void) {
SYS_Initialize( NULL );
//change back to i2c2
I2C2_CallbackRegister(APP_I2C_CALLBACK, 0);
TMR3_Initialize();
TMR2_Initialize();
TMR2_CallbackRegister(Timer2_Handler, 0);
TMR2_Start();
TMR3_Start();
CORETIMER_Initialize();
CORETIMER_Start();
I2C1_Initialize();

TMR3 = 0x0000;
TMR2_InterruptEnable();

GPIO_RE9_Set();
CORETIMER_DelayMs(1000);
GPIO_RE9_Clear();

GPIO_RA9_Set();
CORETIMER_DelayMs(1000);
GPIO_RA9_Clear();

while(true){


    //switch the fan on/off
    sprintf(msgBuffer, "Turning fan on \n\r");
    UART3_Write(&msgBuffer, strlen(msgBuffer)); //unmapped this pin
    GPIO_RE9_Toggle();
    CORETIMER_DelayMs(10); //wait 1 second


    
    sprintf(msgBuffer, "Turning solenoid on \n\r");
    UART3_Write(&msgBuffer, strlen(msgBuffer));
    GPIO_RA9_Toggle();  //
    CORETIMER_DelayMs(2000); //wait 1 second
    
    sprintf(msgBuffer, "Turning fan off \n\r");
    UART3_Write(&msgBuffer, strlen(msgBuffer));
    GPIO_RE9_Toggle();
    CORETIMER_DelayMs(10); //wait 1 second
    
    sprintf(msgBuffer, "Turning solenoid off \n\r");
    UART3_Write(&msgBuffer, strlen(msgBuffer));
    GPIO_RA9_Toggle();
    
    
    
    collectedData[0] = getOxygenData(10, ADDRESS_3);
    char o2Buf[100];
    sprintf(o2Buf, "Oxygen Concentration: %f\n\r", collectedData[0]);
    UART3_Write(&o2Buf, strlen(o2Buf));
    
    collectedData[1] = getCarbonDioxideData();
    char co2Buf[100];
    sprintf(co2Buf, "Carbon Dioxide Concentration: %f\n\r", collectedData[1]);
    UART3_Write(&co2Buf, strlen(co2Buf));
    
    collectedData[2] = readTemperature();
    
    collectedData[3] = readHumidity();
    
    if(GPIO_RB6_Get()==1){
        collectedData[4]=0;
    }
    else{
        collectedData[4]=1;
    }
    char waterLevBuf[100];
    sprintf(waterLevBuf, "Water Level: %f\n\r", collectedData[4]);
    UART3_Write(&waterLevBuf, strlen(waterLevBuf));
    
    collectedData[5] = water_flow;
    char waterFlowBuf[100];
    sprintf(waterFlowBuf, "Water Flow: %f\n\r", collectedData[5]);
    UART3_Write(&waterFlowBuf, strlen(waterFlowBuf));
    

    
    sprintf(msgBuffer, "\n\r");
    UART3_Write(&msgBuffer, strlen(msgBuffer));
    
//    
    CORETIMER_DelayMs(1000); //wait 1 second
//    
//    char o2buf[100];
//    sprintf(o2buf, "Oxygen Buffer: %f%c\n\r", o2val, 37);
//    UART3_Write(&o2buf, strlen(o2buf));
    
    //water level sensor
    //if GPIO_RB6_Get = 1, then there is no water
    //if GPIO_RB6_Get = 0, then there is water
    
//    if(GPIO_RB6_Get()==1){
//        sprintf(msgBuffer, "Low Water!!\n\r");
//        UART3_Write(&msgBuffer, strlen(msgBuffer)); 
//    }

    //    getCarbonDioxideData();

    
//    return_val = return_val * (100.0/2000.0);
//    sprintf(buffer, "CO2 Value: %f percent\n\r", return_val);
//    UART3_Write(&buffer, strlen(buffer));

    
    
    
    
//    char waterBuf[100];
//    sprintf(waterBuf, "Water Freq: %f L/min\n\r", water_flow);
//    UART3_Write(&waterBuf, strlen(waterBuf));
    }
}


/*******************************************************************************
 End of File
*/

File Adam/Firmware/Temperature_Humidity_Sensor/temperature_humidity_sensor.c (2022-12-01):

/* 
 * File:   temperature_humidity_sensor.c
 * Author: Adam Pameron
 *
 * Created on October 24, 2022, 3:00 PM
 */

#include "device.h"
#include "definitions.h"                // SYS function prototypes
#include "temperature_humidity_sensor.h"

// *****************************************************************************
/* Function:
    void setResolution(uint8_t resolution)

  Summary:
    Adjusts resolution of SHT20 Temperature and Humidity Sensor using the
    I2C Peripheral.

  Description:
    This function communicates to the SHT20 Temperature and Humidity Sensor to
    send a command to adjust the sensor's resolution.

  Parameters:
    uint8_t resolution: Adjusted resolution for sensor. All resolution values
    are stored in temperature_humidity_sensor.h.

  Returns:
    None.
*/
void setResolution(uint8_t resolution) {
    uint8_t temp_read_user_reg = READ_USER_REG;
    uint8_t temp_write_user_reg = WRITE_USER_REG;
    uint8_t read_resolution = 0;
    
    I2C1_WriteRead(SHT20_I2C_ADDR, &temp_read_user_reg, 1, &read_resolution, 1);
    
    read_resolution &= 0b01111110;
    resolution &= 0b10000001;
    read_resolution |= resolution;
    
    I2C1_Write(SHT20_I2C_ADDR, &temp_write_user_reg, 1);
    I2C1_Write(SHT20_I2C_ADDR, &read_resolution, 1);
    
}


// *****************************************************************************
/* Function:
    uint8_t checkCRC(uint16_t message_from_sensor, uint8_t check_value_from_sensor)

  Summary:
    Checks whether the retrieved sensor data did no have bit errors.

  Description:
    This function checks whether the first two bytes of data collected from the
    sensor is intact and did not have any bit errors.

  Parameters:
    uint16_t message_from_sensor: MSB and LSB temperature/humidity reading of
    SHT20 sensor.
    uint8_t check_value_from_sensor: Checksum value returned from sensor.

  Returns:
    Returns sensor original sensor reading if there are no bit errors.
*/
uint8_t checkCRC(uint16_t message_from_sensor, uint8_t check_value_from_sensor) {
    uint32_t remainder = (uint32_t)message_from_sensor << 8;
    remainder |= check_value_from_sensor;
    uint32_t divisor = (uint32_t) SHIFTED_DIVISOR;
    int i = 0;
    for(i = 0; i < 16; i++) {
        if(remainder & (uint32_t)1 << (23 - i)) {
            remainder ^= divisor;
        }
        divisor >>= 1;
    }
    return (uint8_t) remainder;
}

// *****************************************************************************
/* Function:
    uint16_t readValue(uint8_t cmd)

  Summary:
    Collects temperature and humidity values using the I2C peripheral and
    verifies if there are any bit errors.

  Description:
    This function communicates to the SHT20 Temperature and Humidity Sensor to
    collect readings for temperature and humidity based on the function command
    sent to the sensor. The retrieved sensor reading is verified with any bit
    errors in case the retrieved data is incorrect.

  Parameters:
    uint8_t cmd: Command request either temperature or humidity reading.

  Returns:
    Temperature or Humidity reading.
*/
uint16_t readValue(uint8_t cmd) {
    uint8_t tempRead[3] = {0};
    I2C1_Write(SHT20_I2C_ADDR, &cmd, 1);
    CORETIMER_DelayMs(200);
    CORETIMER_DelayMs(DELAY_INTERVAL);
    I2C1_Read(SHT20_I2C_ADDR, &tempRead[0], 3);
    while (I2C1_IsBusy())
    {
        // DO NOTHING...
    }
    
    uint8_t msb = tempRead[0];
    uint8_t lsb = tempRead[1];
    uint8_t checksum = tempRead[2];
    
    uint16_t rawValue = ((uint16_t) msb << 8) | (uint16_t) lsb;
    if(checkCRC(rawValue, checksum) != 0) {
        return (ERROR_BAD_CRC);
    }
    return rawValue & 0xFFFC;
}

// *****************************************************************************
/* Function:
   float readTemperature(void)

  Summary:
    Collects temperature values using the I2C peripheral. 

  Description:
    This function communicates to the SHT20 Temperature and Humidity Sensor to
    collect readings for temperature using the readValue function.

  Parameters:
    None.

  Returns:
    Temperature reading.
*/
float readTemperature(void) {
    uint16_t rawTemperature = readValue(TRIGGER_TEMP_MEASURE_NOHOLD);
    char readBuf[100];
    if (rawTemperature == ERROR_I2C_TIMEOUT || rawTemperature == ERROR_BAD_CRC) {
        return rawTemperature;
    }
    float tempTemperature = rawTemperature * (175.72 / 65536.0);
    float realTemperature =  tempTemperature - 46.85;
    sprintf(readBuf, "Real Temperature: %f\n\r", realTemperature);
    UART6_Write(&readBuf, strlen(readBuf));
    return (realTemperature);
}

// *****************************************************************************
/* Function:
   float readHumidity(void)

  Summary:
    Collects humidity values using the I2C peripheral. 

  Description:
    This function communicates to the SHT20 Temperature and Humidity Sensor to
    collect readings for humidity using the readValue function.

  Parameters:
    None.

  Returns:
    Temperature reading.
*/
float readHumidity(void) {
    uint16_t rawHumidity = readValue(TRIGGER_HUMD_MEASURE_NOHOLD);
    if (rawHumidity == ERROR_I2C_TIMEOUT || rawHumidity == ERROR_BAD_CRC) {
        return rawHumidity;
    }
    float tempRH = rawHumidity * (125.0 / 65536.0);
    float rh = tempRH - 6.0;
    char humidBuf[100];
    sprintf(humidBuf, "Raw Humidity: %f\n\r", rh);
    UART6_Write(&humidBuf, strlen(humidBuf));
    return (rh);
}

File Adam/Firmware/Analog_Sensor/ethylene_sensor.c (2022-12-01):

/* 
 * File:   ethylene_sensor.c
 * Author: Adam Pameron and Andrew Yang
 *
 * Created on October 24, 2022, 3:00 PM
 */

#include "device.h"
#include "ethylene_sensor.h"

// *****************************************************************************
/* Function:
    void ethylene_initialize(void)

  Summary:
    Initializes ADC peripheral.

  Description:
    This function configures and initializes the ADC peripheral.

  Parameters:
    None. 

  Returns:
    None.
*/
void ethylene_initialize(void) {
    /* initialize ADC calibration setting */
    ADC0CFG = DEVADC0;
    ADC1CFG = DEVADC1;
    ADC2CFG = DEVADC2;
    ADC3CFG = DEVADC3;
    ADC4CFG = DEVADC4;
//    ADC5CFG = DEVADC5;
//    ADC6CFG = DEVADC6;
    ADC7CFG = DEVADC7;
   /* Configure ADCCON1 */
   ADCCON1 = 0; // No ADCCON1 features are enabled including: Stop-in-Idle, turbo,
   // CVD mode, Fractional mode and scan trigger source.
   /* Configure ADCCON2 */
   ADCCON2 = 0; // Since, we are using only the Class 1 inputs, no setting is
   // required for ADCDIV
   /* Initialize warm up time register */
   ADCANCON = 0;
   ADCANCONbits.WKUPCLKCNT = 5; // Wakeup exponent = 32 * TADx
   /* Clock setting */
   ADCCON3 = 0;
   ADCCON3bits.ADCSEL = 0; // Select input clock source
   ADCCON3bits.CONCLKDIV = 1; // Control clock frequency is half of input clock
   ADCCON3bits.VREFSEL = 0; // Select AVDD and AVSS as reference source
   
   
   /* Select ADC sample time and conversion clock */
   ADC0TIMEbits.ADCDIV = 1; // ADC0 clock frequency is half of control clock = TAD0
   ADC0TIMEbits.SAMC = 5; // ADC0 sampling time = 5 * TAD0
   ADC0TIMEbits.SELRES = 3; // ADC0 resolution is 12 bits
   ADC1TIMEbits.ADCDIV = 1; // ADC1 clock frequency is half of control clock = TAD1
   ADC1TIMEbits.SAMC = 5; // ADC1 sampling time = 5 * TAD1
   ADC1TIMEbits.SELRES = 3; // ADC1 resolution is 12 bits
   ADC2TIMEbits.ADCDIV = 1; // ADC2 clock frequency is half of control clock = TAD2
   ADC2TIMEbits.SAMC = 5; // ADC2 sampling time = 5 * TAD2
   ADC2TIMEbits.SELRES = 3; // ADC2 resolution is 12 bits
   
   
   
   /* Select analog input for ADC modules, no presync trigger, not sync sampling */   
   
   ADCTRGMODEbits.SH0ALT = 0; // ADC0 = AN0
   ADCTRGMODEbits.SH1ALT = 0; // ADC1 = AN1
   ADCTRGMODEbits.SH2ALT = 0; // ADC2 = AN2
   
   /* Select ADC input mode */
   ADCIMCON1bits.SIGN0 = 0; // unsigned data format
   ADCIMCON1bits.DIFF0 = 0; // Single ended mode
   ADCIMCON1bits.SIGN1 = 0; // unsigned data format
   ADCIMCON1bits.DIFF1 = 0; // Single ended mode
   ADCIMCON1bits.SIGN2 = 0; // unsigned data format
   ADCIMCON1bits.DIFF2 = 0; // Single ended mode
   
   ADCIMCON1bits.SIGN6 = 0;
   ADCIMCON1bits.DIFF6 = 0;
   /* Configure ADCGIRQENx */
   ADCGIRQEN1 = 0; // No interrupts are used
   ADCGIRQEN2 = 0;
   /* Configure ADCCSSx */
   ADCCSS1 = 0; // No scanning is used
   ADCCSS2 = 0;
   /* Configure ADCCMPCONx */
   ADCCMPCON1 = 0; // No digital comparators are used. Setting the ADCCMPCONx
   ADCCMPCON2 = 0; // register to '0' ensures that the comparator is disabled.
   ADCCMPCON3 = 0; // Other registers are ?don't care?.
   ADCCMPCON4 = 0;
   ADCCMPCON5 = 0;
   ADCCMPCON6 = 0;
   
   
   /* Configure ADCFLTRx */
    ADCFLTR1 = 0; // No oversampling filters are used.
    ADCFLTR2 = 0;
    ADCFLTR3 = 0;
    ADCFLTR4 = 0;
    ADCFLTR5 = 0;
    ADCFLTR6 = 0;
    /* Set up the trigger sources */
    ADCTRGSNSbits.LVL0 = 0; // Edge trigger
    ADCTRGSNSbits.LVL1 = 0; // Edge trigger
    ADCTRGSNSbits.LVL2 = 0; // Edge trigger
    ADCTRG1bits.TRGSRC0 = 1; // Set AN0 to trigger from software.
    ADCTRG1bits.TRGSRC1 = 1; // Set AN1 to trigger from software.
    ADCTRG1bits.TRGSRC2 = 1; // Set AN2 to trigger from software.
    
    ADCTRGSNSbits.LVL6 = 0;
    ADCTRG2bits.TRGSRC6 = 1;
    /* Early interrupt */
    ADCEIEN1 = 0; // No early interrupt
    ADCEIEN2 = 0;
    /* Turn the ADC on */
    ADCCON1bits.ON = 1;
    /* Wait for voltage reference to be stable */
    while(!ADCCON2bits.BGVRRDY); // Wait until the reference voltage is ready
    while(ADCCON2bits.REFFLT); // Wait if there is a fault with the reference voltage
    /* Enable clock to analog circuit */
    ADCANCONbits.ANEN0 = 1; // Enable the clock to analog bias
//    ADCANCONbits.ANEN1 = 1; // Enable the clock to analog bias
//    ADCANCONbits.ANEN2 = 1; // Enable the clock to analog bias
//    
//    ADCANCONbits.ANEN7 = 1;
    
    /* Wait for ADC to be ready */
    while(!ADCANCONbits.WKRDY0); // Wait until ADC0 is ready
//    while(!ADCANCONbits.WKRDY1); // Wait until ADC1 is ready
//    while(!ADCANCONbits.WKRDY2); // Wait until ADC2 is ready
//    
    while(!ADCANCONbits.WKRDY7);
    
    /* Enable the ADC module */
    ADCCON3bits.DIGEN0 = 1; // Enable ADC0
//    ADCCON3bits.DIGEN1 = 1; // Enable ADC1
//    ADCCON3bits.DIGEN2 = 1; // Enable ADC2
    
    ADCCON3bits.DIGEN7 = 1;
}

// *****************************************************************************
/* Function:
    int getEthyleneData(void)

  Summary:
    Initializes ADC peripheral.

  Description:
    This function sets off a global software trigger  and triggers a conversion.
    After the conversion is complete, the result is collected.

  Parameters:
    None. 

  Returns:
    Digital equivalent of Analog reading.
*/
int getEthyleneData(void) {
    int result[4];
    /* Trigger a conversion */
    ADCCON3bits.GSWTRG = 1;
    /* Wait the conversions to complete */
    while (ADCDSTAT1bits.ARDY0 == 0);
    /* fetch the result */
    result[0] = ADCDATA0;
    while (ADCDSTAT1bits.ARDY1 == 0);
    /* fetch the result */
    result[1] = ADCDATA1;
    while (ADCDSTAT1bits.ARDY2 == 0);
    /* fetch the result */
    result[2] = ADCDATA2;

    while (ADCDSTAT1bits.ARDY6 == 0);
    result[3] = ADCDATA6;

    return result[2];
}

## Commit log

2022-11-12 Create BMS stuff
2022-11-12 Create BMS
2022-11-12 Create Andrew and Rob Analog Sensor Design
2022-11-12 Rename Andrew and Rob Analog Sensor/nice.txt to Andrew and Rob Analog Sensor Design/nice.txt
2022-11-12 Rename Andrew and Rob Analog Sensor Design/nice.txt to Andrew and Rob Analog Sensor Design/Rev 1/Ethylene.txt
2022-11-13 Create Robert Power Management Subsystem
2022-11-13 Update Robert Power Management Subsystem
2022-11-13 Create Future Plans for sensor designs
2022-12-01 Create Power Management details
2022-12-01 Update Power Management details
